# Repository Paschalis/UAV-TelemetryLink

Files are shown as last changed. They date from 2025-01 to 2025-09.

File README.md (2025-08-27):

# Custom RX/TX Board Designs for GCS Communication

<p align="center">
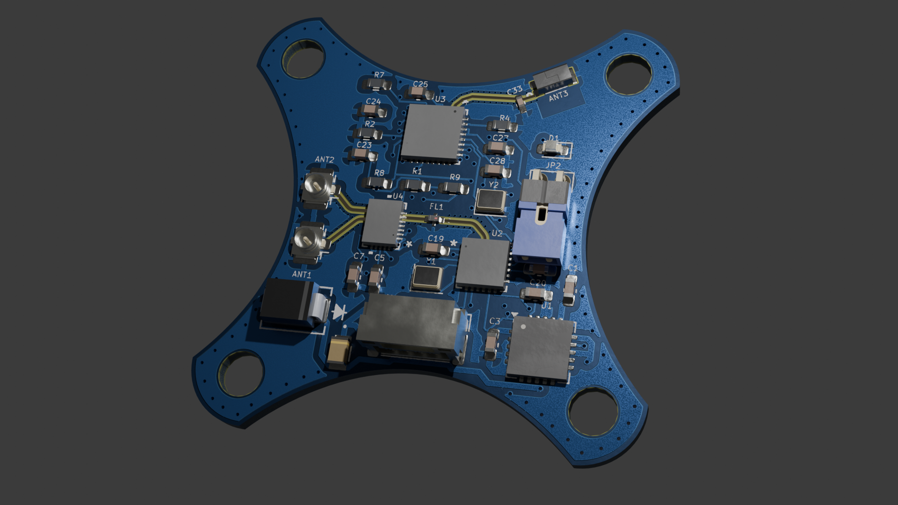
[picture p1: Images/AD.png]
preview
  
</p>

**Receiver and transmitter solution for Ground Control Stations (GCS)**, designed to provide reliable telemetry and control using ELRS, mLRS, and MAVLink protocols. This repository features a wide range of innovative board designs, optimized for long-range communication, minimal latency, and robust performance under varying conditions. From Antenna Diversity to True Diversity and Gemini Mode boards, these designs cater to diverse operational needs and ensure seamless integration with UAV systems. Explore our RX and TX boards tailored to meet the demands of modern UAV telemetry and control systems.

## Table of Contents

1. [QGroundControl Integration](#qgroundcontrol-integration)
2. [Board Designs Overview](#board-designs-overview)
    1. [Antenna Diversity Boards](#1-antenna-diversity-boards)
    - [RX Boards](#rx-boards)
    - [TX Boards](#tx-boards)
    2. [True Diversity or Full Diversity Boards](#2-true-diversity-or-full-diversity-boards)
    - [RX Boards](#rx-boards-1)
    - [TX Boards](#tx-boards-1)
    3. [Gemini Mode Boards](#3-gemini-mode-boards)
    - [RX Boards](#rx-boards-2)
    - [TX Boards](#tx-boards-2)
    4. [Gemini Xrossband (GemX) Boards](#4-gemini-xrossband-gemx-boards)
    - [RX Boards](#rx-boards-3)
    - [TX Boards](#tx-boards-3)
3. [Contributing](#contributing)
4. [Acknowledgments](#acknowledgments)
5. [License](#license)

## QGroundControl Integration

QGroundControl (QGC) is a powerful tool for mission planning and UAV control. This section demonstrates how to use the boards in this repository for telemetry and control with QGC, even without an RC controller.

### Using ELRS Boards with QGC
1. Connect the ground-based ELRS receiver to your GCS using a USB-to-UART adapter.
2. Ensure telemetry is enabled on your flight controller and configured for ELRS.
3. Launch QGC, and verify telemetry data is being received.

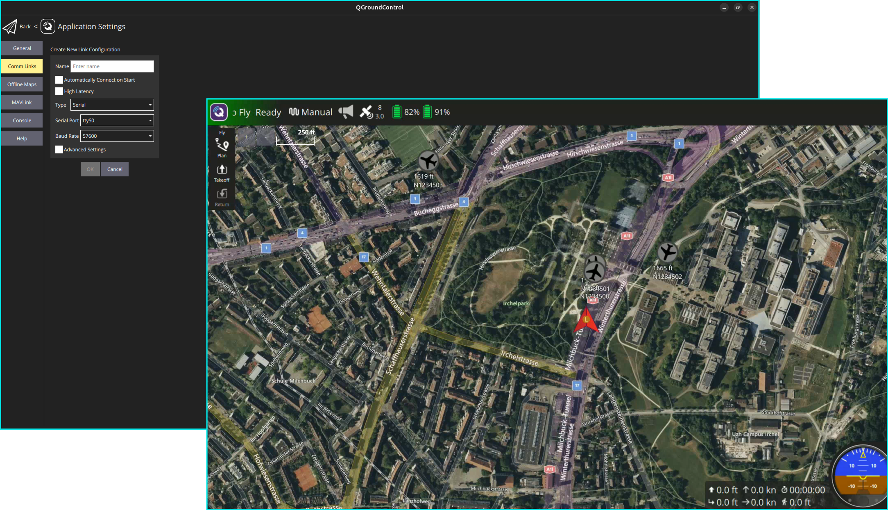
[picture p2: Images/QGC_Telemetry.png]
QGC Interface


### Hardware Setup
Below is an example of the hardware setup for mission planning:
- **Ground Setup**: ELRS transmitter connected to the GCS via USB or mounted on the RC controller.
- **Onboard Setup**: ELRS receiver mounted on the UAV and connected to the flight controller.

Hardware Setup

> **Note:**  
> - More details about the transmission modes can be found in the [Transmission Modes Classification](Receivers%20and%20Transmitters/README.md).
>
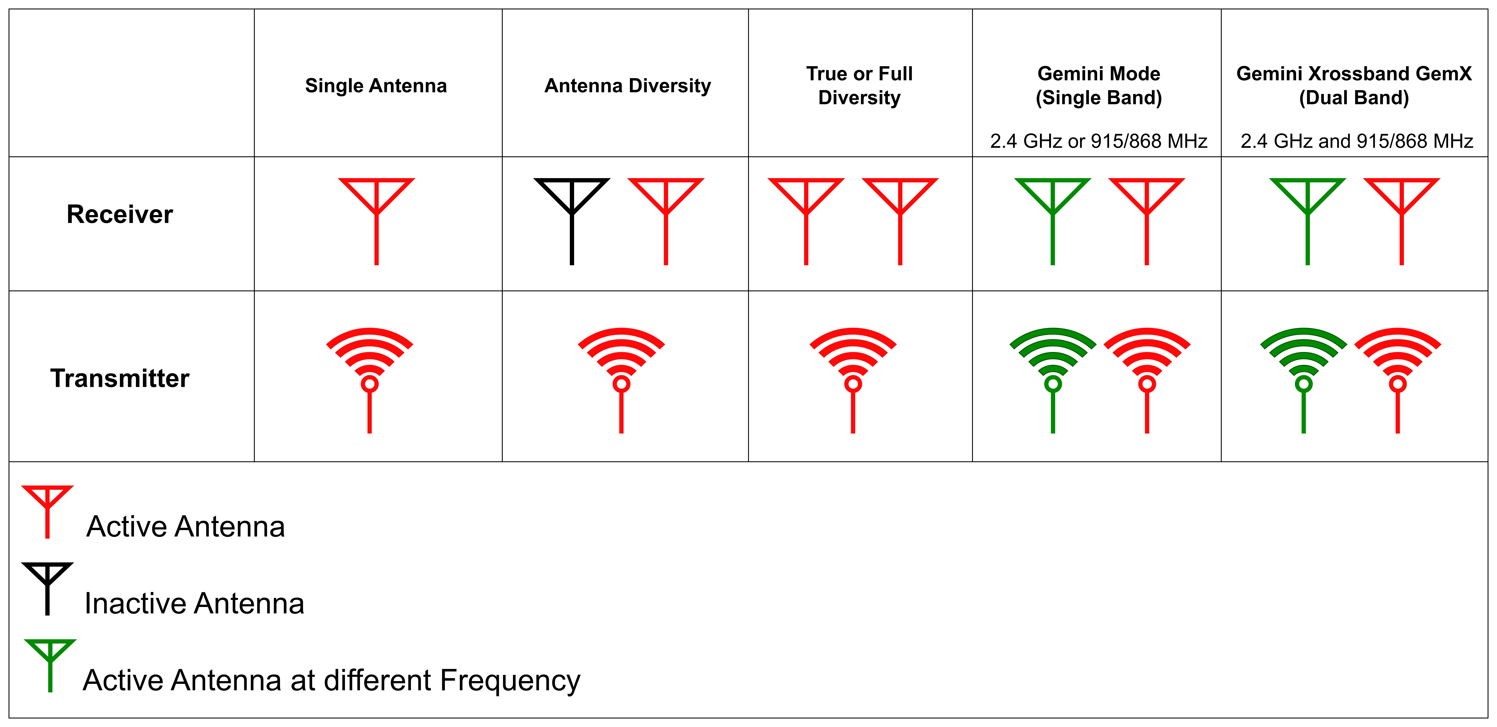
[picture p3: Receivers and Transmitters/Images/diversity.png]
Modes Info
>

> **Note:**  
> - ELRS requires proper binding and configuration to function as a telemetry link.

GCS

## Related Projects (click on them to expand)

<!-- <p align="center"><em>(click on them to expand)</em></p> -->

<ol style="line-height: 2;">
   <li><details open>
   <summary><strong>ESP32 UAV Telemetry Monitor</strong></summary>

An ESP32-based telemetry display system for real-time MAVLink UAV monitoring, featuring a responsive touchscreen interface, live flight status visualization, OTA firmware update capability, and seamless integration with QGroundControl, MAVProxy, and other MAVLink-compatible ground stations.
<div align="center">

MonitorPreview

  
  

</div>

   </details></li>
   <li><details>
   <summary><strong>FC Plus Sensor Module</strong></summary>


FC Plus Sensor Module is a modular add-on board for UAV flight controllers, offering advanced features such as telemetry, GPS, object avoidance (ToF, Sonar, IR), and LED indicators for status feedback. This repository includes comprehensive documentation, hardware setup instructions, sensor integration guides, and communication protocols (LoRa/WiFi) to improve UAV autonomy, safety, and performance.

<div align="center">

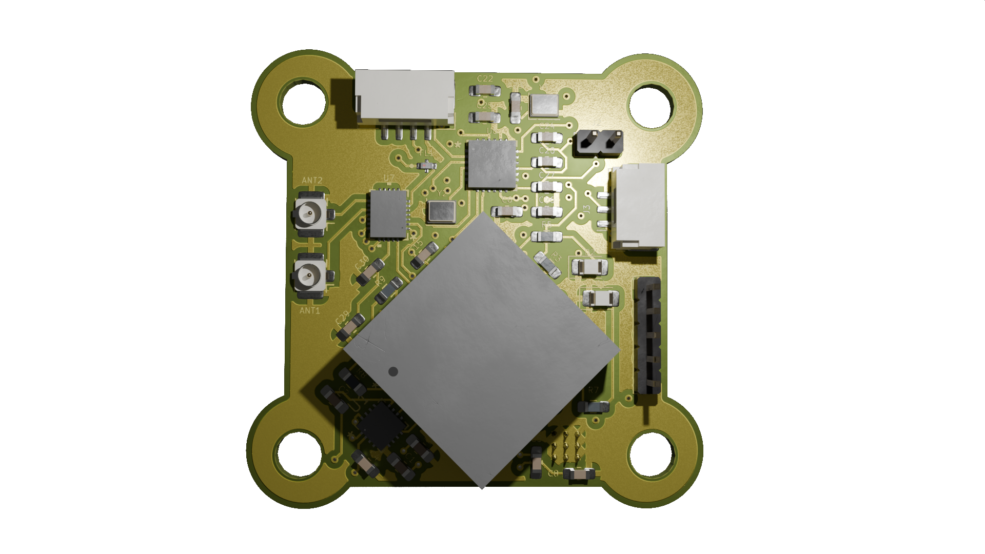
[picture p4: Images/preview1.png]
FCreview



              
  

</div>

</ol>

# Board Designs Overview

This repository contains a collection of designs for RX and TX boards under different transmission modes. More details about the transmission modes can be found in the [Transmission Modes Classification](Receivers%20and%20Transmitters/README.md).

<p align="center">
    <a href="https://Paschalis.github.io/UAV-TelemetryLink/" target="_blank">
        
    </a>
</p>

<div style="overflow-x:auto;">

### 1. Antenna Diversity Boards

### RX Boards

#### ELRS

| Name | Frequency | Version | Features | Media | Status |
|---|---|---|---|---|---|
| AD1_2.4G  | 2.4GHz | Rev 1.0 | Basic diversity setup | <p align="center">Preview<br/> </p> | <p align="center">✅ Approved</p> |
| AD2_900M  | 900MHz | Rev — | (Add description) | <p align="center">Preview<br/>(Add links)</p> | <p align="center">Draft</p> |

</div>

<div style="overflow-x:auto;">

## 2. True Diversity or Full Diversity Boards

### RX Boards

| Name | Frequency | Version | Features | Media | Status |
|---|---|---|---|---|---|
| TD1_2.4G  | 2.4GHz | Rev 1.0 | Full diversity with improved range | <p align="center">Preview<br/> </p> | <p align="center">✅ Approved</p> |
| TD2_900M  | 900MHz | Rev 0.9 | (Add description) | <p align="center">Preview<br/>(Add links)</p> | <p align="center">Draft</p> |

</div>

## TX Boards (Shared for Single Antenna, Antenna Diversity & True Diversity)
<div align="center">

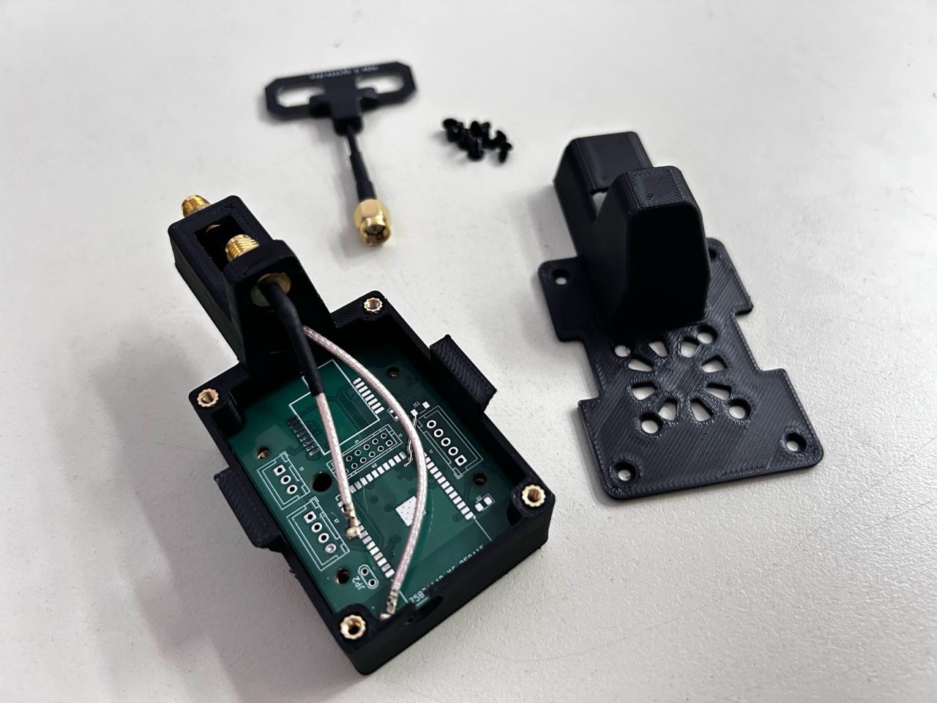
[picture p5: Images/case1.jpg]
MonitorPreview


[📂 Click here to open the enclosure files](https://github.com/Paschalis/UAV-TelemetryLink/tree/main/Receivers%20and%20Transmitters/Transmitters/Mechanical%20CAD)

MonitorPreview

</div>

> **Note:**  
> The TX boards listed in this section are shared across **Single Antenna Mode, Antenna Diversity, and True Diversity** configurations.  
> - These boards are **not duplicated** under each diversity category to avoid redundancy.  
> - They are optimized for their respective frequencies (**2.4GHz** & **900MHz**) and ensure compatibility across all three configurations.  
> - **Gemini Mode (GM) and Gemini Xrossband (GemX) have their own TX boards**, so they are listed separately in their respective sections.  

<div style="overflow-x:auto;">

### TX Boards  

| Name | Frequency | Version | Features | Media | Status |
|---|---|---|---|---|---|
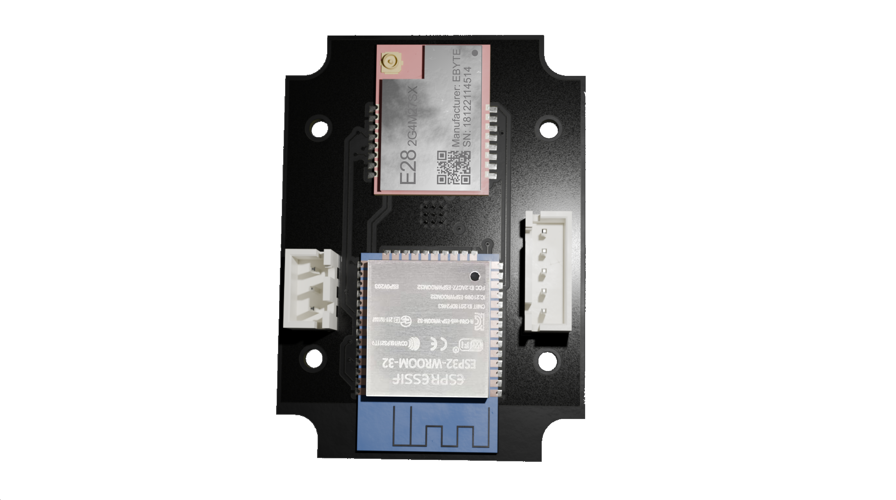
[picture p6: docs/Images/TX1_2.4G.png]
| TX1_2.4G  | 2.4GHz | Rev 1.0 | Basic transmitter with no OLED display or TX Backpack. | <p align="center"><br/> </p> | <p align="center">✅ Approved</p> |
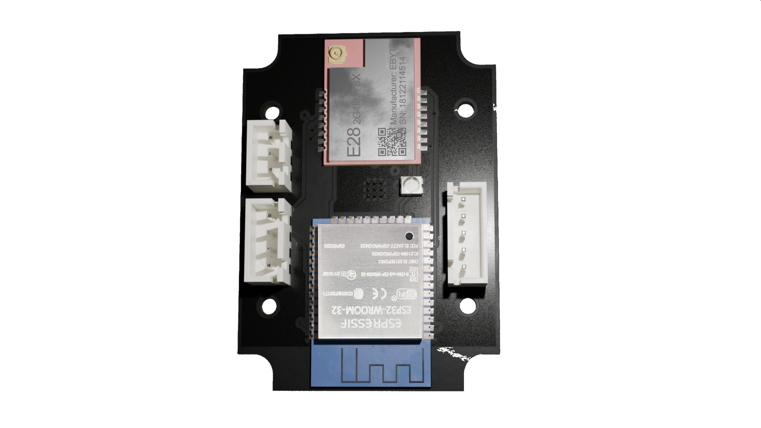
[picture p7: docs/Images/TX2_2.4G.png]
| TX2_2.4G  | 2.4GHz | Rev 1.1 | Includes SSD1306 OLED display, but no TX Backpack. | <p align="center"><br/> </p> | <p align="center">✅ Approved</p> |
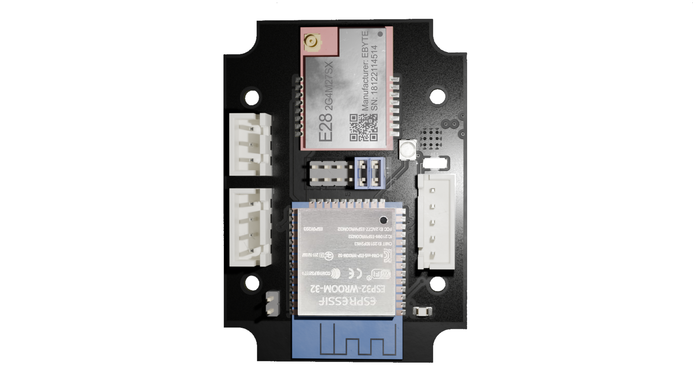
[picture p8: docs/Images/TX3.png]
| TX3_2.4G  | 2.4GHz | Rev 1.2 | Features both SSD1306 OLED display and TX Backpack for GCS communication.| <p align="center"><br/> </p> | <p align="center">Draft</p> |
| TX1_900M  | 900MHz | Rev 1.0 | Robust transmitter for 900MHz band, suitable for longer-range links. | <p align="center">Preview<br/> </p> | <p align="center">Draft</p> |

</div>

## 3. Gemini Mode Boards  

### RX Boards
> **Note:**  
> - The **Gemini RX boards** are actually the **True Diversity RX boards** operating in **Gemini Mode**.  
> - To enable **Gemini Mode**, set the **RX Antenna Mode** to **Gemini** via Lua script.  
> - **Single Antenna RX boards** can also operate in Gemini Mode but must use **Model 5** in **Model Config Matching** via Lua script.  
> - **Gemini-capable receivers** should use **Model 6** in **Model Config Matching**.  
> - Click on [🔗 **Go to True Diversity Full Diversity RX Boards**](#2-true-diversity-or-full-diversity-boards) to view compatible receivers.  
>  
> 📖 **Reference:** [ExpressLRS Gemini Mode Documentation](https://www.expresslrs.org/software/gemini/#what-is-gemini)  

<div style="overflow-x:auto;">

### TX Boards (Gemini Mode – Single Band)

| Name | Frequency | Version | Features | Media | Status |
|---|---|---|---|---|---|
| G_TX1_2.4G  | 2.4GHz | Rev 1.0 | Sends packets on two frequencies ~40 MHz apart in the 2.4 GHz band. | <p align="center">Preview<br/> </p> | <p align="center">✅ Approved</p> |
| G_TX1_900M  | 900MHz | Rev 1.0 | Sends packets on two frequencies ~10 MHz apart in the 900 MHz band. | <p align="center">Preview<br/> </p> | <p align="center">Draft</p> |

</div>

<div style="overflow-x:auto;">

## 4. Gemini Xrossband (GemX) Boards  

### RX Boards  

| Name  | Frequency | Version | Features | Media | Status |
|---|---|---|---|---|---|
| GX1 | 2.4GHz & 900MHz  | Rev 1.0 | Crossband receiver for 2.4GHz and 900MHz | <p align="center">Preview (https://github.com/your-repo/boards/GX1)<br/> </p> | <p align="center">Draft</p> |

### TX Boards  

| Name | Frequency | Version | Features | Media | Status |
|---|---|---|---|---|---|
| GX_TX1 | 2.4GHz & 900MHz  | Rev 1.0 | Crossband transmitter for 2.4GHz and 900MHz | <p align="center">Preview (https://github.com/your-repo/boards/GX_TX1)<br/> </p> | <p align="center">Draft</p> |

</div>

## Contributing

Feel free to contribute to this repository by submitting pull requests for new board designs or updates to existing ones.

## Acknowledgments

We would like to thank the following for making this project possible:

- **ELRS (ExpressLRS)**: High-performance, low-latency long-range communication for UAVs.  
- **mLRS (MAVLink Long Range System)**: MAVLink-based long-range telemetry and control extension for ELRS.  
- **MAVLink**: The essential protocol for UAV communication and mission control.  
- **QGroundControl (QGC)**: Open-source ground control software for UAV mission planning. 
- **OpenTX**: Open-source firmware for RC transmitters, enabling extensive customization and telemetry support.  
- **OpenI6X**: A custom OpenTX / EdgeTX port for the Flysky FS-i6X transmitter, expanding its capabilities and MAVLink support.   
- **Other Contributors**: Thanks to all who contributed feedback, bug fixes, and improvements.

These open-source tools and protocols are integral to the success of this project.

## License

This project is licensed under the following:

- **Hardware Designs**: MIT License - see the [LICENSE-HARDWARE](LICENSE-HARDWARE) file for details.
- **Firmware/Software**: GPLv3 License - see the [LICENSE-FIRMWARE](LICENSE-FIRMWARE) file for details.

> **Note:**  
> The firmware you flash onto the hardware uses the **ELRS** and **mLRS**, which are licensed under **GPLv3**. Any modifications or redistribution of the firmware must comply with the terms of the **GPLv3** license.

---

**Thank you for visiting UAV-TelemetryLink!**

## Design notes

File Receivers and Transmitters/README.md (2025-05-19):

# Transmission Modes Classification

Gemini Info

This document describes various transmission modes used in long-range LoRa (Long Range) wireless communication for drones. These modes leverage LoRa's unique capabilities to improve Signal Quality (LQ), mitigate interference, and enhance reliability over extended distances, making them ideal for drone applications in diverse environments.

## Transmission Modes

### 1. Single Antenna
- **Description**:  
  Uses one antenna on both the transmitter and receiver, operating over a single frequency channel.
- **Advantages**:  
  - Simplicity  
  - Low cost  
- **Limitations**:  
  - Highly susceptible to interference and signal loss.  

### 2. Antenna Diversity
- **Description**:  
  The receiver employs two antennas to select the best signal, while the transmitter uses a single antenna. Communication occurs over a single frequency channel.  
- **Advantages**:  
  - Improved signal quality due to antenna selection.  
- **Limitations**:  
  - Only one frequency channel is used.  
  - Transmission lacks diversity.  

### 3. True Diversity or Full Diversity
- **Description**:  
  Both the transmitter and receiver utilize two independent Semtech LoRa chips, each connected to its own antenna, operating on the same frequency. This setup provides full diversity for both transmitting and receiving.  
- **Advantages**:  
  - Enhanced signal quality through full transmitter and receiver diversity.  
  - Redundancy in signal transmission and reception.  
- **Limitations**:  
  - Increased complexity and cost.  

### 4. Gemini Mode (Single Band)
- **Description**:  
  The transmitter sends packets on two frequencies within the same band (e.g., 2.4 GHz or 900 MHz), spaced approximately 40 MHz apart for 2.4 GHz and 10 MHz apart for 900 MHz. A true diversity receiver with two antennas and LoRa chips receives both signals simultaneously.  
- **Advantages**:  
  - Superior interference mitigation by utilizing two frequencies within the same band.  
  - Improved stability and reliability of signal quality.  
- **Limitations**:  
  - Limited to a single frequency band.  

### 5. Gemini Xrossband GemX (Dual Band)
- **Description**:  
  The transmitter operates simultaneously on two different frequency bands (e.g., 2.4 GHz and 900 MHz), each managed by independent LoRa chips. The receiver employs true diversity hardware with two antennas and LoRa chips operating on distinct bands.  
- **Advantages**:  
  - Enhanced interference avoidance by operating across separate bands.  
  - Increased performance and redundancy for long-range communication.  
- **Limitations**:  
  - More complex and expensive hardware due to dual-band operation.  

## Transmission Mode Classification Chart

| Mode | Frequency Channels | Antennas (TX) | Antennas (RX)| Interference Mitigation | Signal Quality  | Receiver Type |
|---|---|---|---|---|---|---|
| **Single Antenna** | 1 | 1 | 1 | Low | Low | Simple Receiver |
| **Antenna Diversity** | 1 | 1 | 2 | Moderate | Moderate | Diversity Receiver |
| **True Diversity or Full Diversity**  | 1 | 1 | 2 | High | High | Diversity Receiver |
| **Gemini Mode (Single Band)**| 2 (within 1 band) | 2 | 2 | Very High | Very High | Diversity Receiver |
| **Gemini Xrossband GemX (Dual Band)** | 2 (across 2 bands) | 2 | 2 | Excellent | Excellent | Dual-band Receiver |

## Summary

This classification illustrates the progression from basic single antenna setups to advanced true diversity and dual-band configurations:

- **Single Antenna** and **Antenna Diversity** provide fundamental solutions suitable for simple environments.  
- **True Diversity** or **Full Diversity** and **Gemini Mode (Single Band)** offer significant enhancements in reliability and interference mitigation within the same band.  
- **Gemini Xrossband GemX (Dual Band)** delivers optimal performance by leveraging dual-band communication, ideal for complex and interference-prone environments.  

Understanding these modes enables the selection of appropriate communication systems tailored to specific drone operation requirements, ensuring robust and efficient wireless links.

## Mounting and Enclosure Options

For practical deployment of the transmission systems described above, especially those involving Moxon or omnidirectional antennas operating at 2.4 GHz and 900 MHz, refer to the [TX_Enclosures_RC_Mounts](/Receivers%20and%20Transmitters/Transmitters/TX_Enclosures_RC_Mounts/) folder.

This directory contains 3D-printable enclosures and RC controller mounting designs for various transmitter boards. These mounts are optimized for signal performance, mechanical stability, and operator ergonomics across all transmission modes, from single antenna to Gemini Xrossband setups.

---

## References

- [mLRS GitHub Repository](https://github.com/olliw42/mLRS)  
- [mLRS Documentation](https://github.com/olliw42/mLRS-docu)  
- [mLRS Hardware Repository](https://github.com/olliw42/mLRS-hardware/tree/master)  
- [ArduPilot: mLRS RC Overview](https://ardupilot.org/copter/docs/common-mlrs-rc.html)  
- [ExpressLRS: Gemini Overview](https://www.expresslrs.org/software/gemini/)  
- [ExpressLRS Documentation](https://www.expresslrs.org/)  

[⬅️ Go Back to Main README](../README.md)

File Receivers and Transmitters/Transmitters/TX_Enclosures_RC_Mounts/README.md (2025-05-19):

# TX Enclosures and RC Controller Mounts

This folder contains 3D-printable enclosures and mounting systems for transmitter boards used in long-range LoRa communication systems. These designs are intended to be mounted securely on RC controllers or other ground station platforms, ensuring optimal antenna placement, signal integrity, and protection of the electronics.

## 📦 Included Designs

Each mount or enclosure is optimized for both mechanical stability and RF performance, and is designed to accommodate the following:

- **Transmitter types:**
  - TX1, TX2, TX3 (2.4GHz)
  - G_TX1 (Gemini 2.4GHz / 900MHz)
  - GX_TX1 (Gemini Xrossband 2.4GHz + 900MHz)

- **Antenna support:**
  - Moxon directional antennas (for reduced side lobe interference)
  - Omnidirectional vertical whips (for all-direction reception)
  - Mounts for both upright and tilted antenna positions

## 📐 File Format Notes

- Files are provided in `.STL` format for direct 3D printing.
- - Some designs also include `.STEP`, `.Fusion360`, or SolidWorks-compatible files (`.SLDPRT`, `.SLDASM`) for customization.
- Be sure to orient the print flat on the base and use moderate infill (25–40%) for strength without excessive weight.

## Previews

## License

All 3D models and designs are released under the [CERN Open Hardware License v2](https://ohwr.org/project/cernohl/wikis/home), allowing you to modify, share, and produce them for personal or commercial use, provided attribution is given and derivatives are shared alike.

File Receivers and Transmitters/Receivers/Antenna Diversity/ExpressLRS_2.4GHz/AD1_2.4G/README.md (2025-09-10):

<div align="center">

# AD1_2.4G

Antenna Diversity 
(Basic diversity setup)

</div>

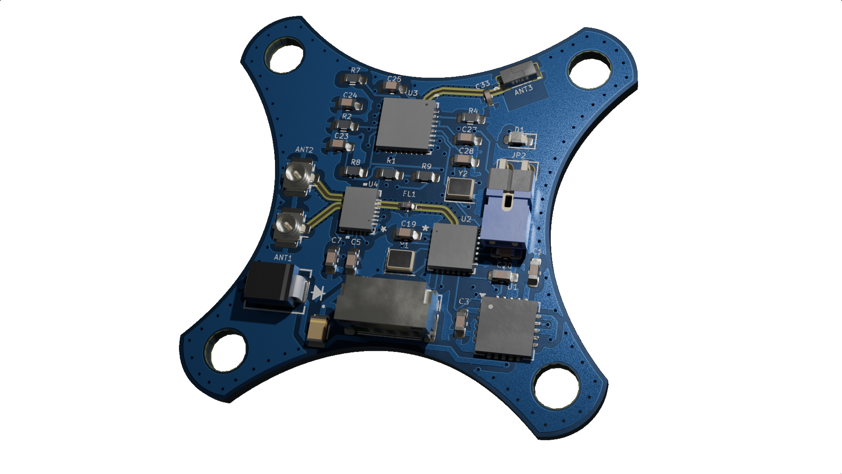
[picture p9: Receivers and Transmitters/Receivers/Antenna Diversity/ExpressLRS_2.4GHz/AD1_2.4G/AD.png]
Board Preview


<p align="center"><a href="https://paschalis.github.io/UAV-TelemetryLink/ibom/AD1_2.4G.html">iBOM</a> or <a href="https://kicanvas.org/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">KiCanvas</a></p>  <p align="center">Click the icons to open iBOM or KiCanvas</p> 

## Bill of Materials

| **Reference** | **Value** | **Datasheet** | **Footprint** | **Qty** | **DNP** |
|---|---|---|---|---|---|
| AE1 | Antenna | ~ | RF_Antenna:Texas_SWRA117D_2.4GHz_Right | 1  | |
| ANT1, ANT2  | Conn_Coaxial | ~ | Connector_Coaxial:U.FL_Hirose_U.FL-R-SMT-1_Vertical | 2  | |
| C1, C30, C32 | 10uF | ~ | Capacitor_SMD:C_0805_2012Metric_Pad1.18x1.45mm_HandSolder,ECASD40J106M055K00:ECASD40J106M055K00 | 3  | |
| C2 | 1uF | ~ | Capacitor_SMD:C_0805_2012Metric_Pad1.18x1.45mm_HandSolder | 1  | |
| C3 | 47uF | ~ | Capacitor_SMD:C_0805_2012Metric_Pad1.18x1.45mm_HandSolder | 1  | |
| C4 | 2.2uF | ~ | Capacitor_SMD:C_0805_2012Metric_Pad1.18x1.45mm_HandSolder | 1  | |
| C5, C6, C21, C22 | 10pF | ~ | Capacitor_SMD:C_0805_2012Metric_Pad1.18x1.45mm_HandSolder | 4  | |
| C7, C16, C17, C23, C24, C25, C26, C27, C28, C29 | 100nF | ~ | Capacitor_SMD:C_0805_2012Metric_Pad1.18x1.45mm_HandSolder | 10 | |
| C18 | 470nF | ~ | Capacitor_SMD:C_0805_2012Metric_Pad1.18x1.45mm_HandSolder | 1  | |
| C19, C20 | 10nF | ~ | Capacitor_SMD:C_0805_2012Metric_Pad1.18x1.45mm_HandSolder | 2  | |
| C31 | 0.1uF | ~ | Capacitor_SMD:C_0805_2012Metric_Pad1.18x1.45mm_HandSolder | 1  | |
| D1 | LED | ~ | LED_SMD:LED_0805_2012Metric_Pad1.15x1.40mm_HandSolder | 1  | |
| FL1 | 2450FM07D0034T  | [Datasheet](https://www.mouser.co.uk/datasheet/2/611/2450FM07D0034-1375634.pdf) | 2450FM07D0034T:2450FM07D0034T | 1 | |
| J1 | Conn_01x04_Socket | ~ | Connector_Harwin:Harwin_M20-89004xx_1x04_P2.54mm_Horizontal | 1  | |
| J3 | Conn_01x04_Pin  | ~ | Connector_JST:JST_GH_SM04B-GHS-TB_1x04-1MP_P1.25mm_Horizontal | 1  | |
| JP1 | Jumper_2_Bridged | ~ | TestPoint:TestPoint_2Pads_Pitch2.54mm_Drill0.8mm | 1  | |
| R1 | 2.2K | ~ | Resistor_SMD:R_0805_2012Metric_Pad1.20x1.40mm_HandSolder | 1  | |
| R2, R3, R7, R8, R10 | 10K | ~ | Resistor_SMD:R_0805_2012Metric_Pad1.20x1.40mm_HandSolder | 5  | |
| R4 | 12K | ~ | Resistor_SMD:R_0805_2012Metric_Pad1.20x1.40mm_HandSolder | 1  | |
| R5 | 0 | ~ | Resistor_SMD:R_0805_2012Metric_Pad1.20x1.40mm_HandSolder | 1  | |
| R6 | 1K | ~ | Resistor_SMD:R_0805_2012Metric_Pad1.20x1.40mm_HandSolder | 1  | |
| R9 | 1.2K | ~ | Resistor_SMD:R_0805_2012Metric_Pad1.20x1.40mm_HandSolder | 1  | |
| U1 | TPS7A4701xRGW | [Datasheet](https://www.ti.com/lit/ds/symlink/tps7a47.pdf) | Package_DFN_QFN:Texas_RGW0020A_VQFN-20-1EP_5x5mm_P0.65mm_EP3.15x3.15mm_ThermalVias | 1 | |
| U2 | SX1280IMLTRT | SX1280IMLTRT | SX1280IMLTRT:QFN24_4X4_SEM | 1 | |
| U3 | ESP8285H16 | ESP8285H16 | ESP8285H16:QFN32_5X5_EXP | 1 | |
| U4 | SE2431L-R | SE2431L-R | SE2431L-R:SE2431L_SKY | 1 | |
| Y1 | 52MHz | ~ | Crystal:Crystal_SMD_2016-4Pin_2.0x1.6mm | 1 | |
| Y2 | 26MHz | ~ | Crystal:Crystal_SMD_2016-4Pin_2.0x1.6mm | 1 | |

[⬅️ Go Back to Main README](https://github.com/Paschalis/UAV-TelemetryLink)

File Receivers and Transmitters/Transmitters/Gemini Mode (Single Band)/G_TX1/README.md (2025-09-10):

<div align="center">

# G_TX1 at 2.4G

TRANSMITTER BOARD
(Gemini Mode Compatible)

</div>

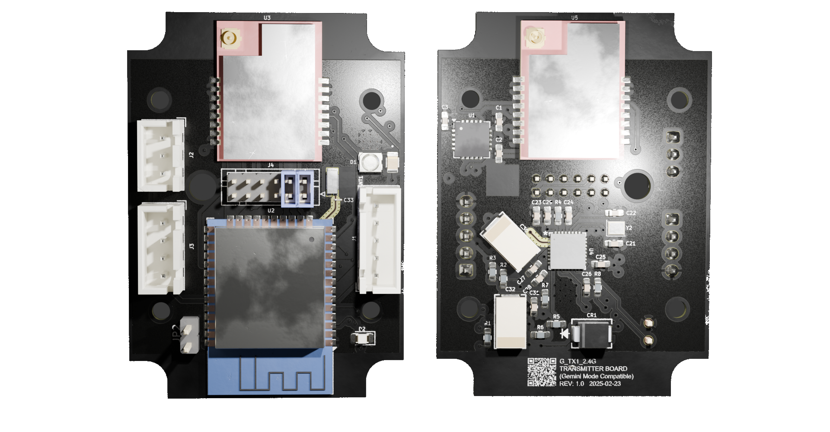
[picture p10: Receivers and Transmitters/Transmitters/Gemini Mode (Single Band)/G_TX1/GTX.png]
Board Preview

<p align="center"><a href="https://paschalis.github.io/UAV-TelemetryLink/ibom/G_TX1_2.4G.html">iBOM</a> or <a href="https://kicanvas.org/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">KiCanvas</a></p>  <p align="center">Click the icons to open iBOM or KiCanvas</p> 

[⬅️ Go Back to Main README](https://github.com/Paschalis/UAV-TelemetryLink)

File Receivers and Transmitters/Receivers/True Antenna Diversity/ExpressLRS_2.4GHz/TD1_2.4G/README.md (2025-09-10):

<div align="center">

# TD1 at 2.4G

True Diversity or Full Diversity
(Full diversity with improved range)

</div>

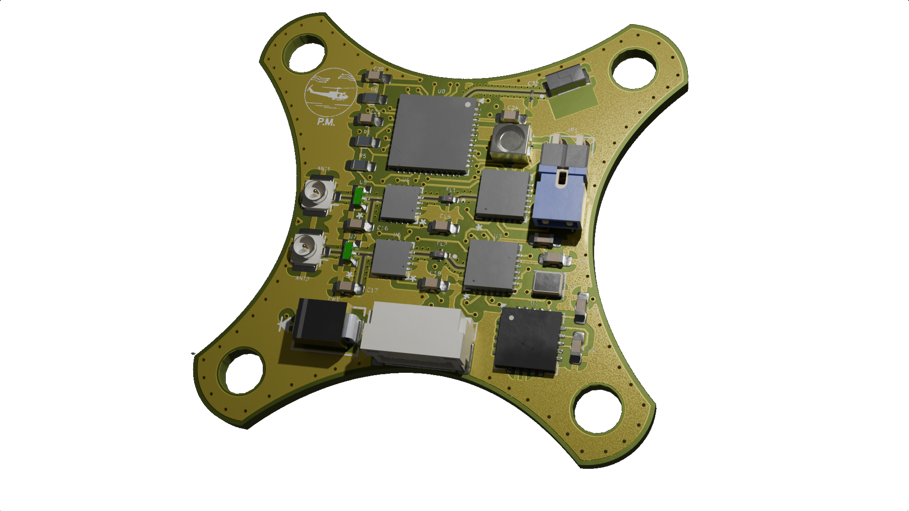
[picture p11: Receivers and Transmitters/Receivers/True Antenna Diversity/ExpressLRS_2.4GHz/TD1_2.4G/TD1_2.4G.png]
Board Preview

<p align="center"><a href="https://paschalis.github.io/UAV-TelemetryLink/ibom/TD1_2.4G.html">iBOM</a> or <a href="https://kicanvas.org/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">KiCanvas</a></p>  <p align="center">Click the icons to open iBOM or KiCanvas</p> 

[⬅️ Go Back to Main README](https://github.com/Paschalis/UAV-TelemetryLink)

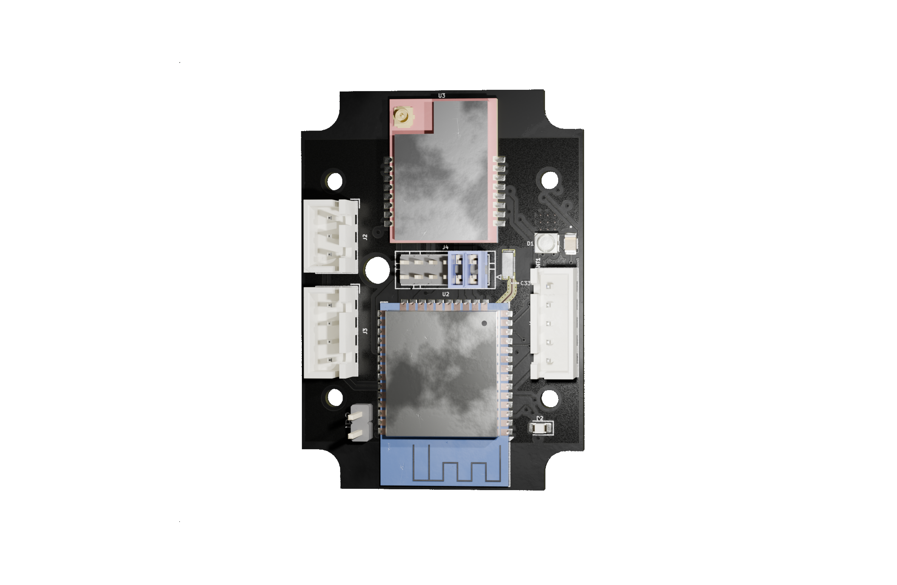
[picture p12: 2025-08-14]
docs/Images/G_TX1_2.4G.png

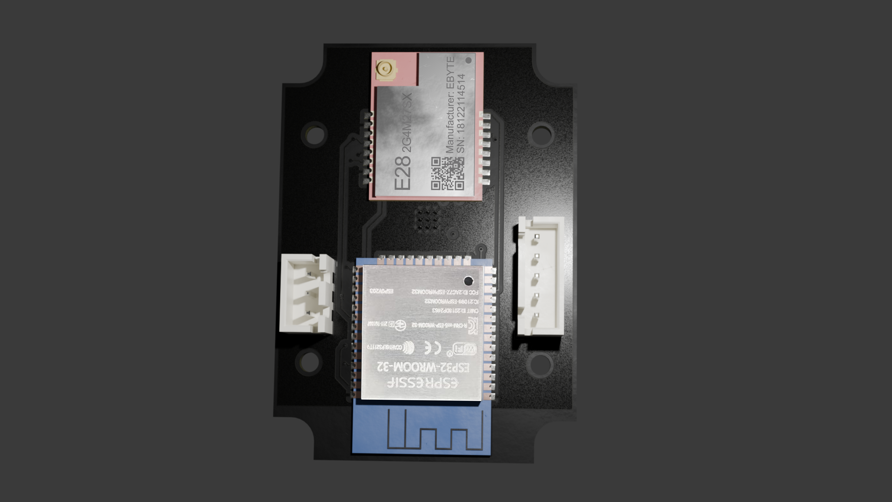
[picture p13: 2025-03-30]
Receivers and Transmitters/Transmitters/Shared for Single Antenna, Antenna Diversity, True or Full Diversity/ExpressLRS_2.4GHz/TX1_2.4G/TX1.png

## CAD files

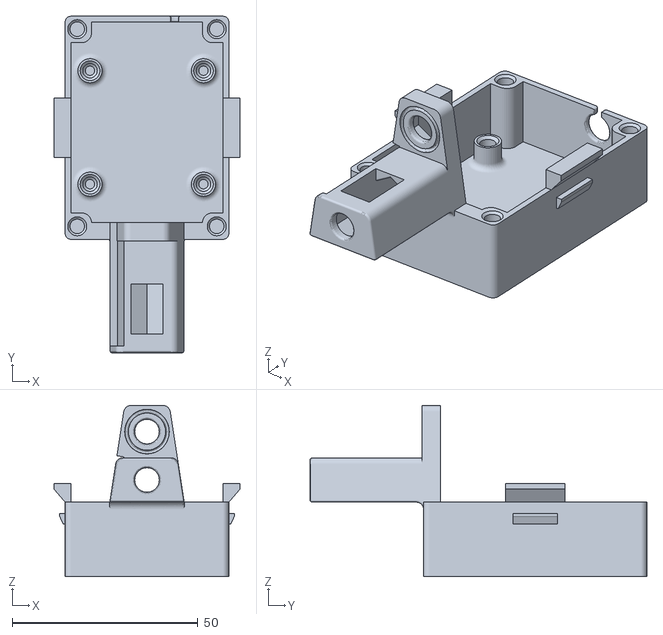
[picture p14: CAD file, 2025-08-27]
Receivers and Transmitters/Transmitters/Mechanical CAD/Enclosure_Bottom.stl
50.0 x 90.5 x 46.0

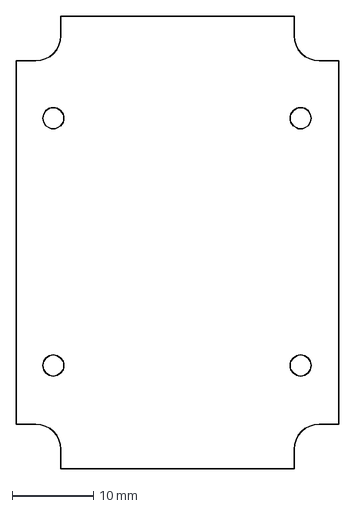
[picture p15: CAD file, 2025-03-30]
Receivers and Transmitters/Transmitters/PCB outline/(PCB outline) V1_Matek_mLRS-JRBay-btm (with PCB mounting).DXF
39.8 x 55.8 mm

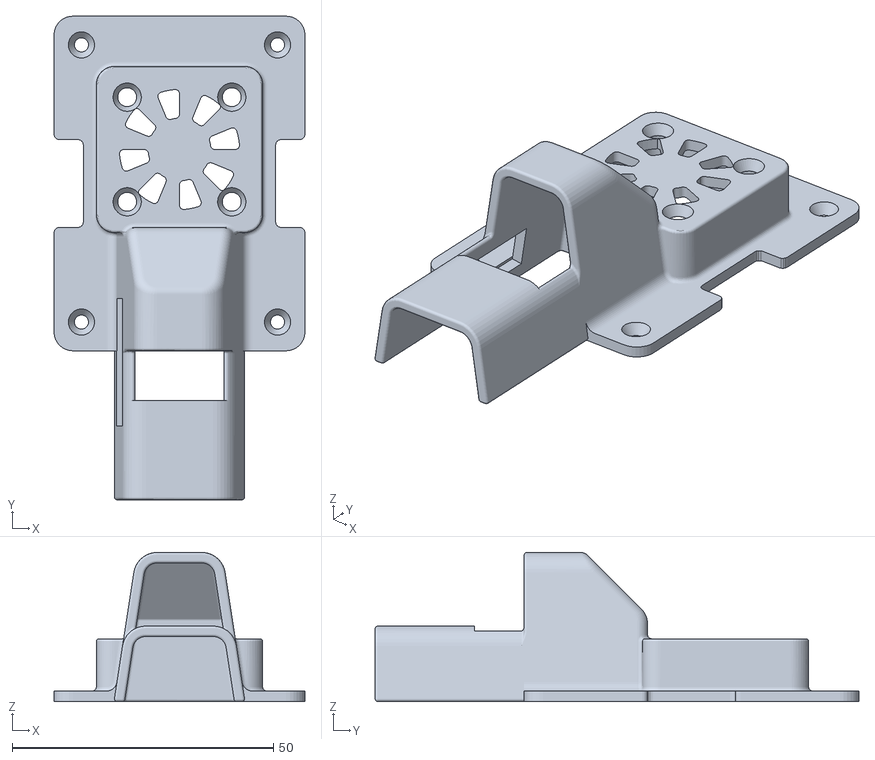
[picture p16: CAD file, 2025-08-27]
Receivers and Transmitters/Transmitters/Mechanical CAD/Enclosure_Top.stl
48.0 x 92.5 x 28.5

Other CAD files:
Receivers and Transmitters/Transmitters/Mechanical CAD/V1.2 (Top_Bottom_Offset)_mLRS-JRBay-btm.STL

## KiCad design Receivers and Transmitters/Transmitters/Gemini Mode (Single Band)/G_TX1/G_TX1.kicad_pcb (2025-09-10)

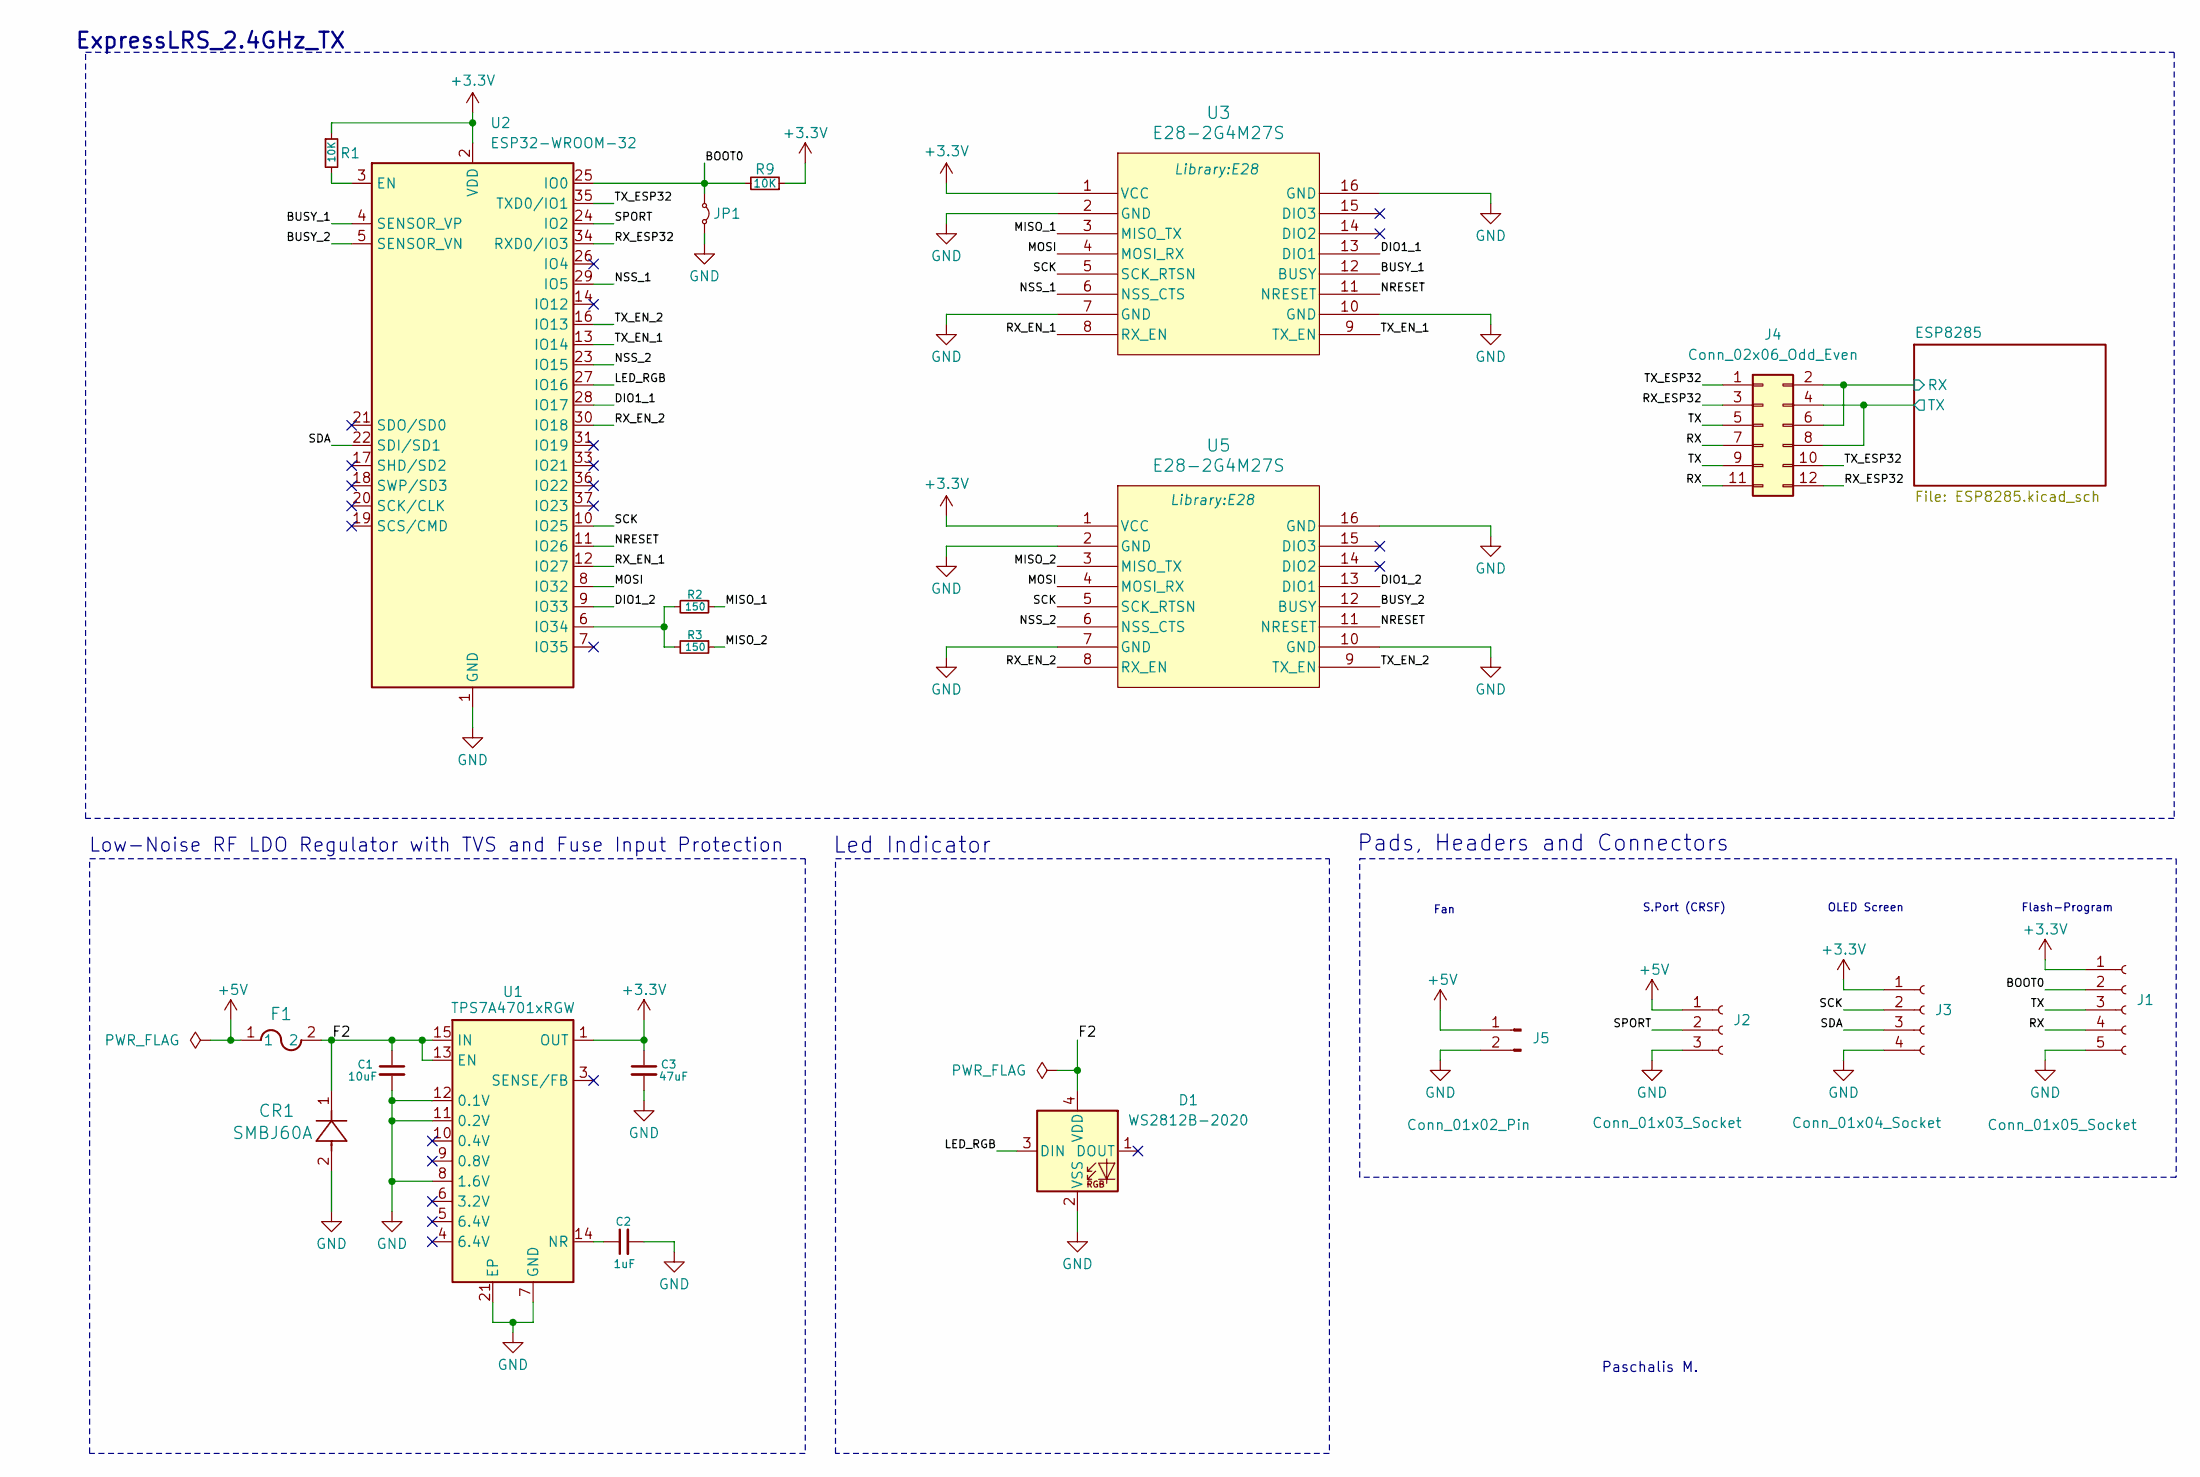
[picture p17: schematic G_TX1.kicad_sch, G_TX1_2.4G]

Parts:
C1: 10uF; C_0603_1608Metric_Pad1.08x0.95mm_HandSolder
C2: 1uF; C_0603_1608Metric_Pad1.08x0.95mm_HandSolder
C3: 47uF; C_0603_1608Metric_Pad1.08x0.95mm_HandSolder
CR1: SMBJ60A; SMBJSeries_LTF
D1: WS2812B-2020; LED_WS2812B-2020_PLCC4_2.0x2.0mm
F1: MF-PSMF020X-2; FUSE_F020X_BRN
J1: Conn_01x05_Socket; JST_XH_B5B-XH-A_1x05_P2.50mm_Vertical
J2: Conn_01x03_Socket; JST_XH_B3B-XH-A_1x03_P2.50mm_Vertical
J3: Conn_01x04_Socket; JST_XH_B4B-XH-A_1x04_P2.50mm_Vertical
J4: Conn_02x06_Odd_Even; JST_PHD_B12B-PHDSS_2x06_P2.00mm_Vertical
J5: Conn_01x02_Pin; PinHeader_1x02_P2.00mm_Vertical
JP1: Jumper_2_Small_Bridged; TestPoint_2Pads_Pitch2.54mm_Drill0.8mm
R1, R9: 10K; R_0603_1608Metric_Pad0.98x0.95mm_HandSolder
R2, R3: 150; R_0603_1608Metric_Pad0.98x0.95mm_HandSolder
U1: TPS7A4701xRGW; Texas_RGW0020A_VQFN-20-1EP_5x5mm_P0.65mm_EP3.15x3.15mm_Ther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
U2: ESP32-WROOM-32
U3, U5: E28-2G4M27S; E28

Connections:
+3.3V: C3.1, J1.1, J3.1, R1.1, R9.1, U1.1 (OUT), U1.20 (OUT), U2.2 (VDD), U3.1 (VCC), U5.1 (VCC); also elsewhere on the board
+5V: F1.1, J2.1, J5.1
/BOOT0: J1.2, JP1.1 (A), R9.2, U2.25 (IO0)
/BUSY_1: U2.4 (SENSOR_VP), U3.12 (BUSY)
/BUSY_2: U2.5 (SENSOR_VN), U5.12 (BUSY)
/DIO1_1: U2.28 (IO17), U3.13 (DIO1)
/DIO1_2: U2.9 (IO33), U5.13 (DIO1)
/ESP8285/RX: J4.2, J4.6; also elsewhere on the board
/ESP8285/TX: J4.4, J4.8; also elsewhere on the board
/F2: C1.1, CR1.1, D1.4 (VDD), F1.2, U1.13 (EN), U1.15 (IN), U1.16 (IN)
/LED_RGB: D1.3 (DIN), U2.27 (IO16)
/MISO_1: R2.1, U3.3 (MISO_TX)
/MISO_2: R3.1, U5.3 (MISO_TX)
/MOSI: U2.8 (IO32), U3.4 (MOSI_RX), U5.4 (MOSI_RX)
/NRESET: U2.11 (IO26), U3.11 (NRESET), U5.11 (NRESET)
/NSS_1: U2.29 (IO5), U3.6 (NSS_CTS)
/NSS_2: U2.23 (IO15), U5.6 (NSS_CTS)
/RX: J1.4, J4.7, J4.11
/RX_EN_1: U2.12 (IO27), U3.8 (RX_EN)
/RX_EN_2: U2.30 (IO18), U5.8 (RX_EN)
/RX_ESP32: J4.3, J4.12, U2.34 (RXD0/IO3)
/SCK: J3.2, U2.10 (IO25), U3.5 (SCK_RTSN), U5.5 (SCK_RTSN)
/SDA: J3.3, U2.22 (SDI/SD1)
/SPORT: J2.2, U2.24 (IO2)
/TX: J1.3, J4.5, J4.9
/TX_EN_1: U2.13 (IO14), U3.9 (TX_EN)
/TX_EN_2: U2.16 (IO13), U5.9 (TX_EN)
/TX_ESP32: J4.1, J4.10, U2.35 (TXD0/IO1)
GND: C1.2, C2.2, C3.2, CR1.2, D1.2 (VSS), J1.5, J2.3, J3.4, J5.2, JP1.2 (B), U1.7 (GND), U1.8 (1.6V), U1.11 (0.2V), U1.12 (0.1V), U1.21 (EP), U2.1 (GND), U2.15 (GND), U2.38 (GND), U2.39 (GND), U3.2 (GND), U3.7 (GND), U3.10 (GND), U3.16 (GND), U5.2 (GND), U5.7 (GND), U5.10 (GND), U5.16 (GND); also elsewhere on the board
unnamed: C2.1, U1.14 (NR)
unnamed: R1.2, U2.3 (EN)
unnamed: R2.2, R3.2, U2.6 (IO34)

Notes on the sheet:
S.Port (CRSF)
Low-Noise RF LDO Regulator with TVS and Fuse Input Protection
Paschalis M.
Led Indicator
Flash-Program
OLED Screen
Fan
Pads, Headers and Connectors
ExpressLRS_2.4GHz_TX

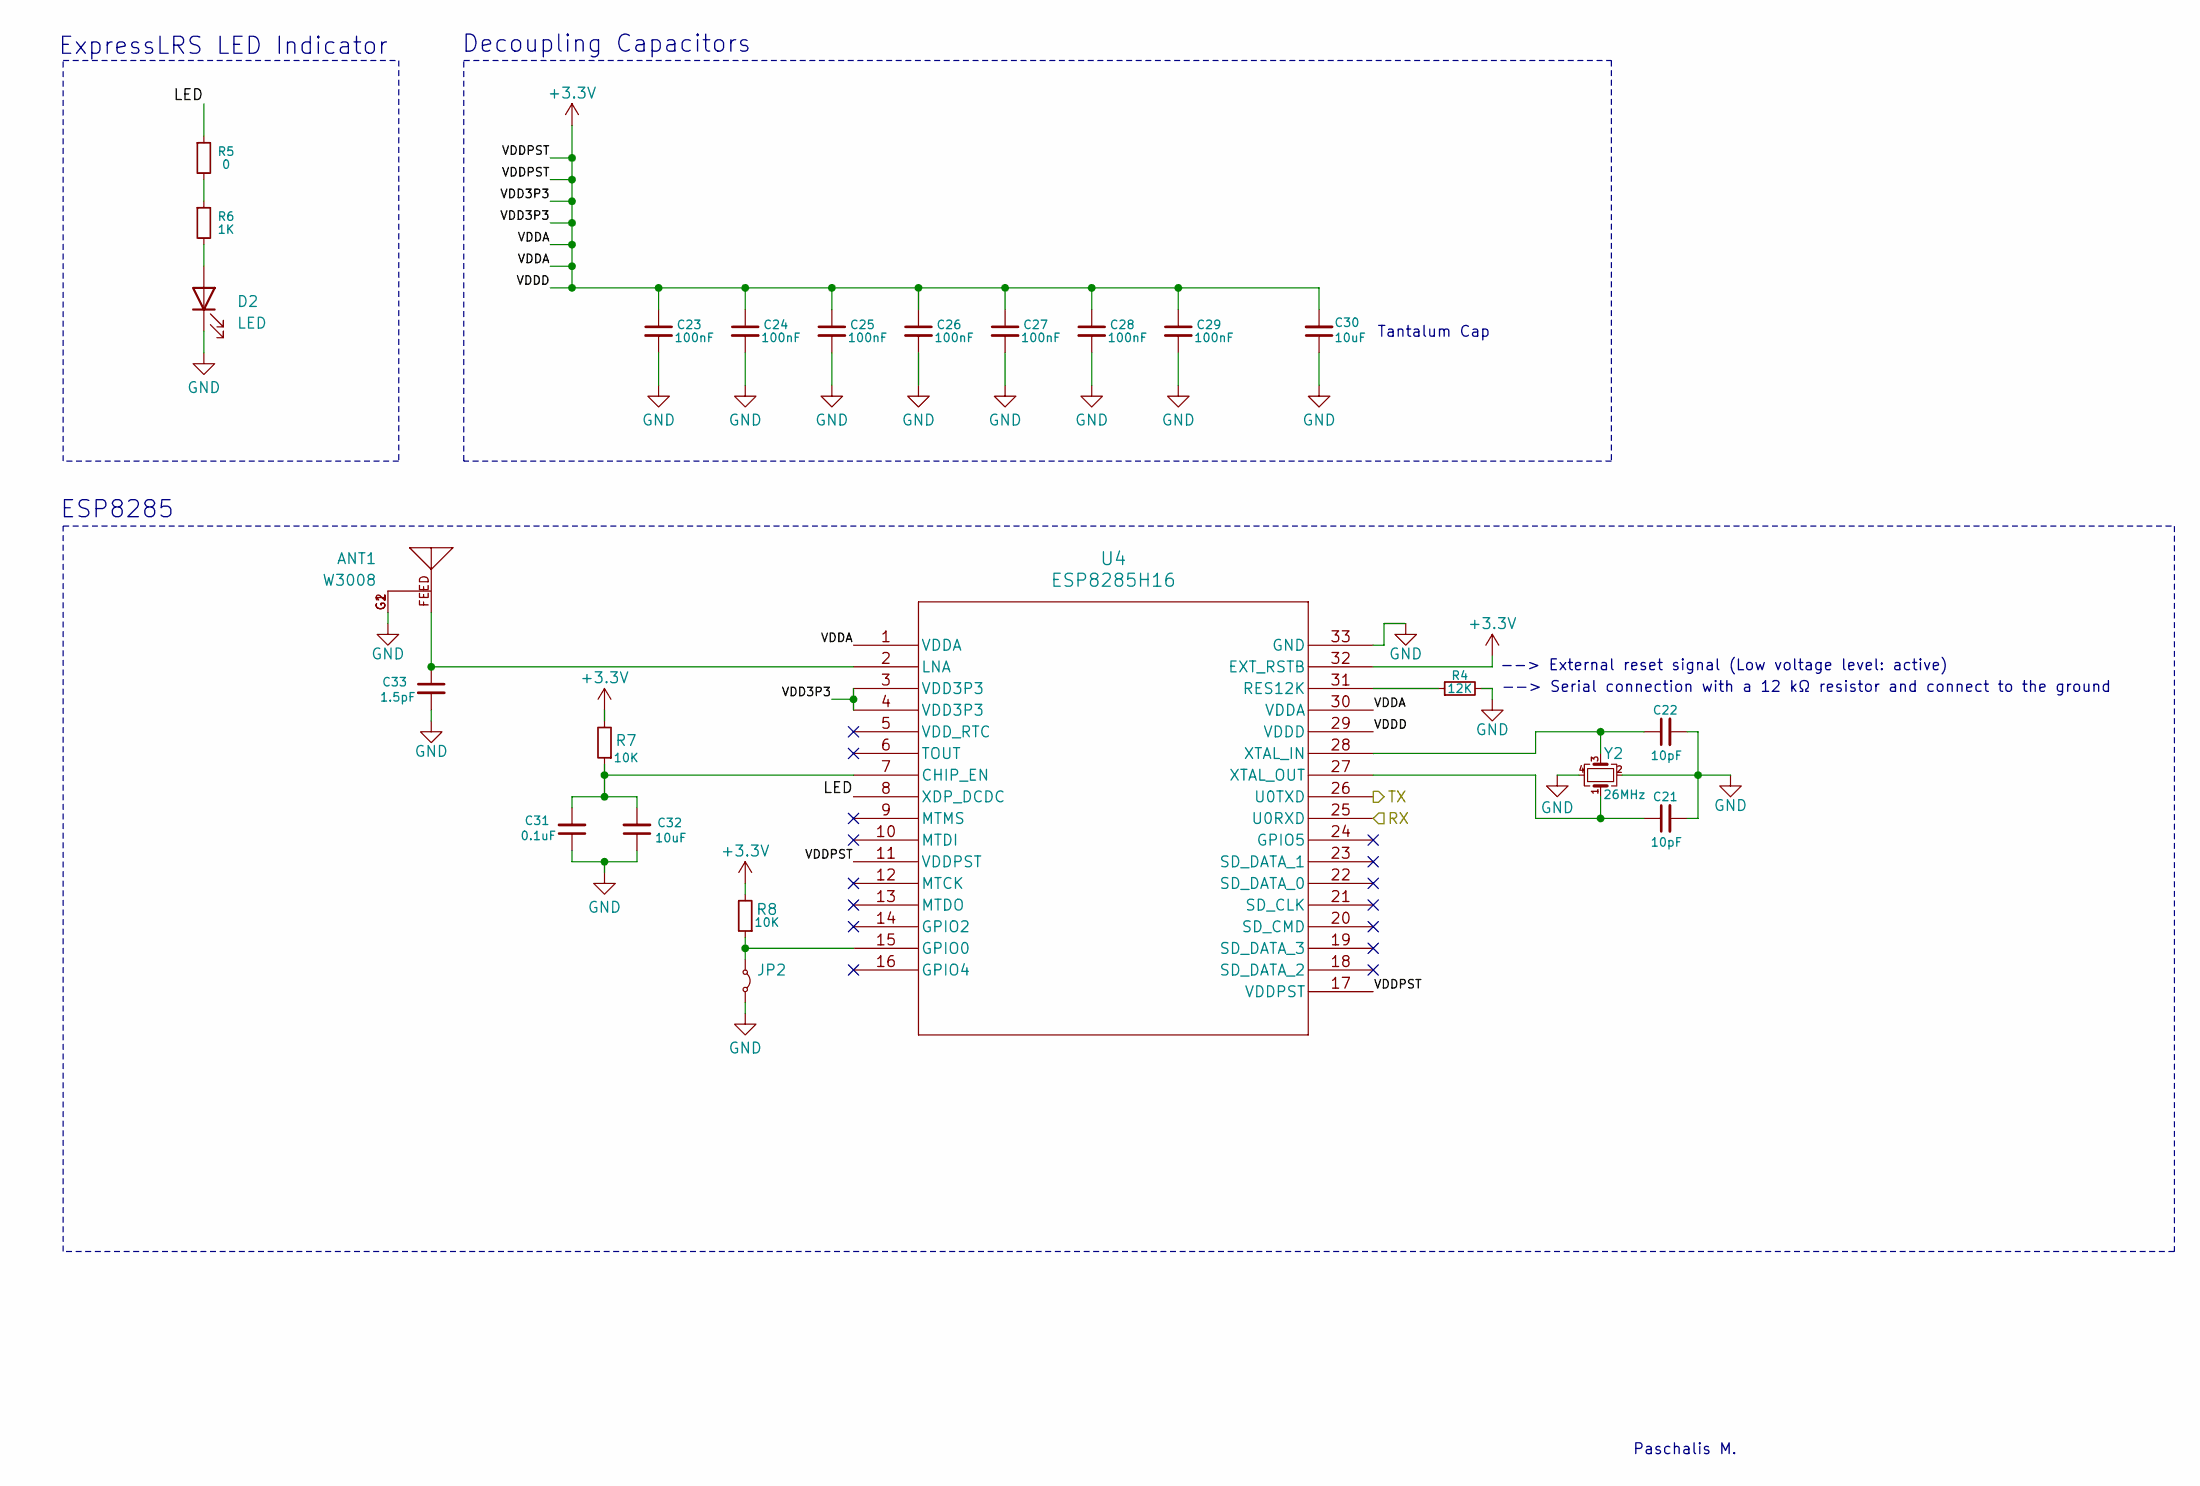
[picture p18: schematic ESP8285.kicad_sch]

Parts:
ANT1: W3008; ANTENNA_W3008
C21, C22: 10pF; C_0603_1608Metric_Pad1.08x0.95mm_HandSolder
C23, C24, C25, C26, C27, C28, C29: 100nF; C_0603_1608Metric_Pad1.08x0.95mm_HandSolder
C30, C32: 10uF; ECASD40J106M055K00
C31: 0.1uF; C_0603_1608Metric_Pad1.08x0.95mm_HandSolder
C33: 1.5pF; C_01005_0402Metric_Pad0.57x0.30mm_HandSolder
D2: LED; LED_0805_2012Metric_Pad1.15x1.40mm_HandSolder
JP2: Jumper_2_Small_Bridged; TestPoint_2Pads_Pitch2.54mm_Drill0.8mm
R4: 12K; R_0603_1608Metric_Pad0.98x0.95mm_HandSolder
R5: 0; R_0603_1608Metric_Pad0.98x0.95mm_HandSolder
R6: 1K; R_0603_1608Metric_Pad0.98x0.95mm_HandSolder
R7, R8: 10K; R_0603_1608Metric_Pad0.98x0.95mm_HandSolder
U4: ESP8285H16; QFN32_5X5_EXP
Y2: 26MHz; Crystal_SMD_2016-4Pin_2.0x1.6mm

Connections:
+3.3V: C23.1, C24.1, C25.1, C26.1, C27.1, C28.1, C29.1, C30.2, R7.2, R8.2, U4.1 (VDDA), U4.3 (VDD3P3), U4.4 (VDD3P3), U4.11 (VDDPST), U4.17 (VDDPST), U4.29 (VDDD), U4.30 (VDDA), U4.32 (EXT_RSTB); also elsewhere on the board
/ESP8285/LED: R5.1, U4.8 (XDP_DCDC)
/ESP8285/RX: U4.25 (U0RXD); also elsewhere on the board
/ESP8285/TX: U4.26 (U0TXD); also elsewhere on the board
GND: ANT1.G1, ANT1.G2, C21.2, C22.2, C23.2, C24.2, C25.2, C26.2, C27.2, C28.2, C29.2, C30.1, C31.1, C32.1, C33.2, D2.1 (K), JP2.2 (B), R4.2, U4.33 (GND), Y2.2, Y2.4; also elsewhere on the board
unnamed: D2.2 (A), R6.2
unnamed: JP2.1 (A), R8.1, U4.15 (GPIO0)
unnamed: R5.2, R6.1
unnamed: C31.2, C32.2, R7.1, U4.7 (CHIP_EN)
unnamed: ANT1.FEED, C33.1, U4.2 (LNA)
unnamed: R4.1, U4.31 (RES12K)
unnamed: C22.1, U4.28 (XTAL_IN), Y2.3
unnamed: C21.1, U4.27 (XTAL_OUT), Y2.1

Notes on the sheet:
--> External reset signal (Low voltage level: active)
--> Serial connection with a 12 kΩ resistor and connect to the ground
Decoupling Capacitors
Paschalis M.
ESP8285
Tantalum Cap
ExpressLRS LED Indicator

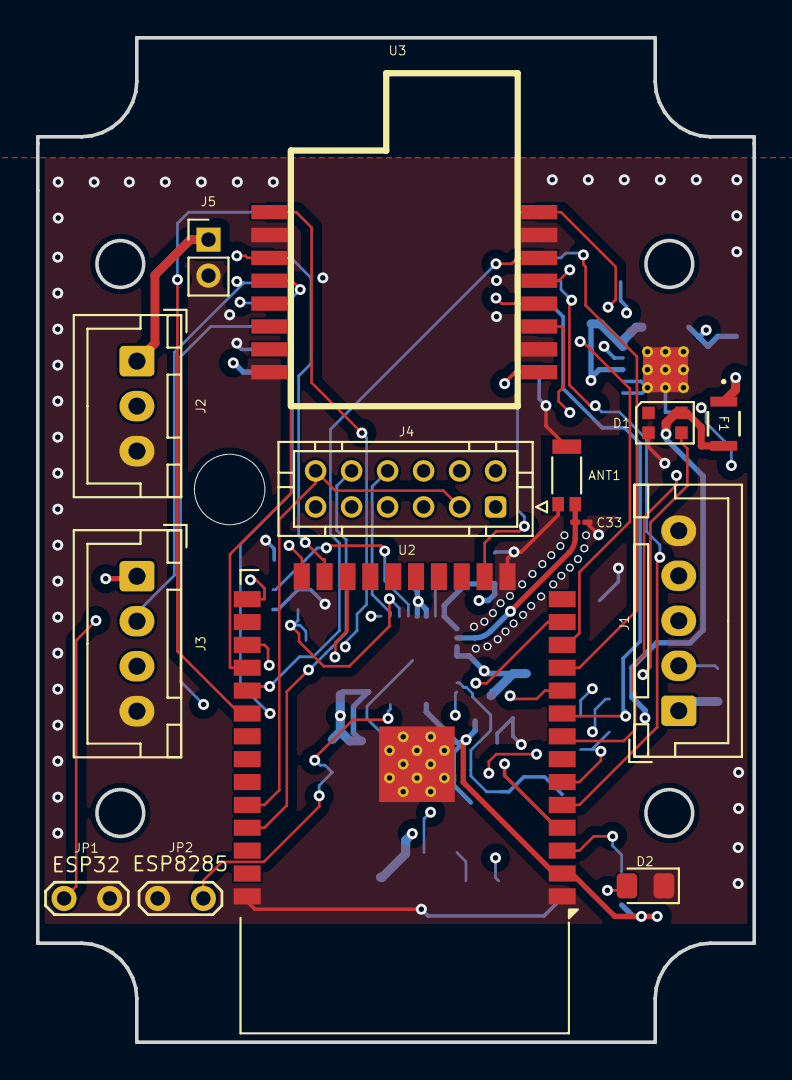
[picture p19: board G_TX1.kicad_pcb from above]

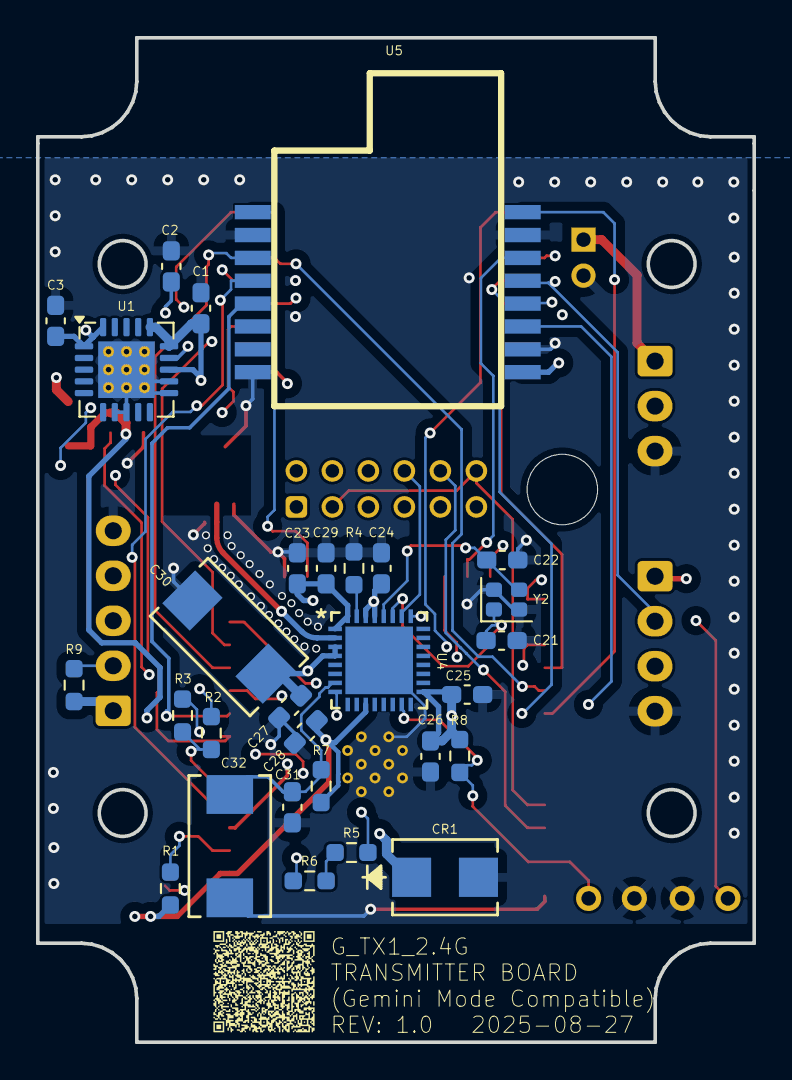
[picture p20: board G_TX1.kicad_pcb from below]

Board: 6 copper layers, 39.8 x 55.8 mm, 43 parts (29 on the bottom side), 41 nets.

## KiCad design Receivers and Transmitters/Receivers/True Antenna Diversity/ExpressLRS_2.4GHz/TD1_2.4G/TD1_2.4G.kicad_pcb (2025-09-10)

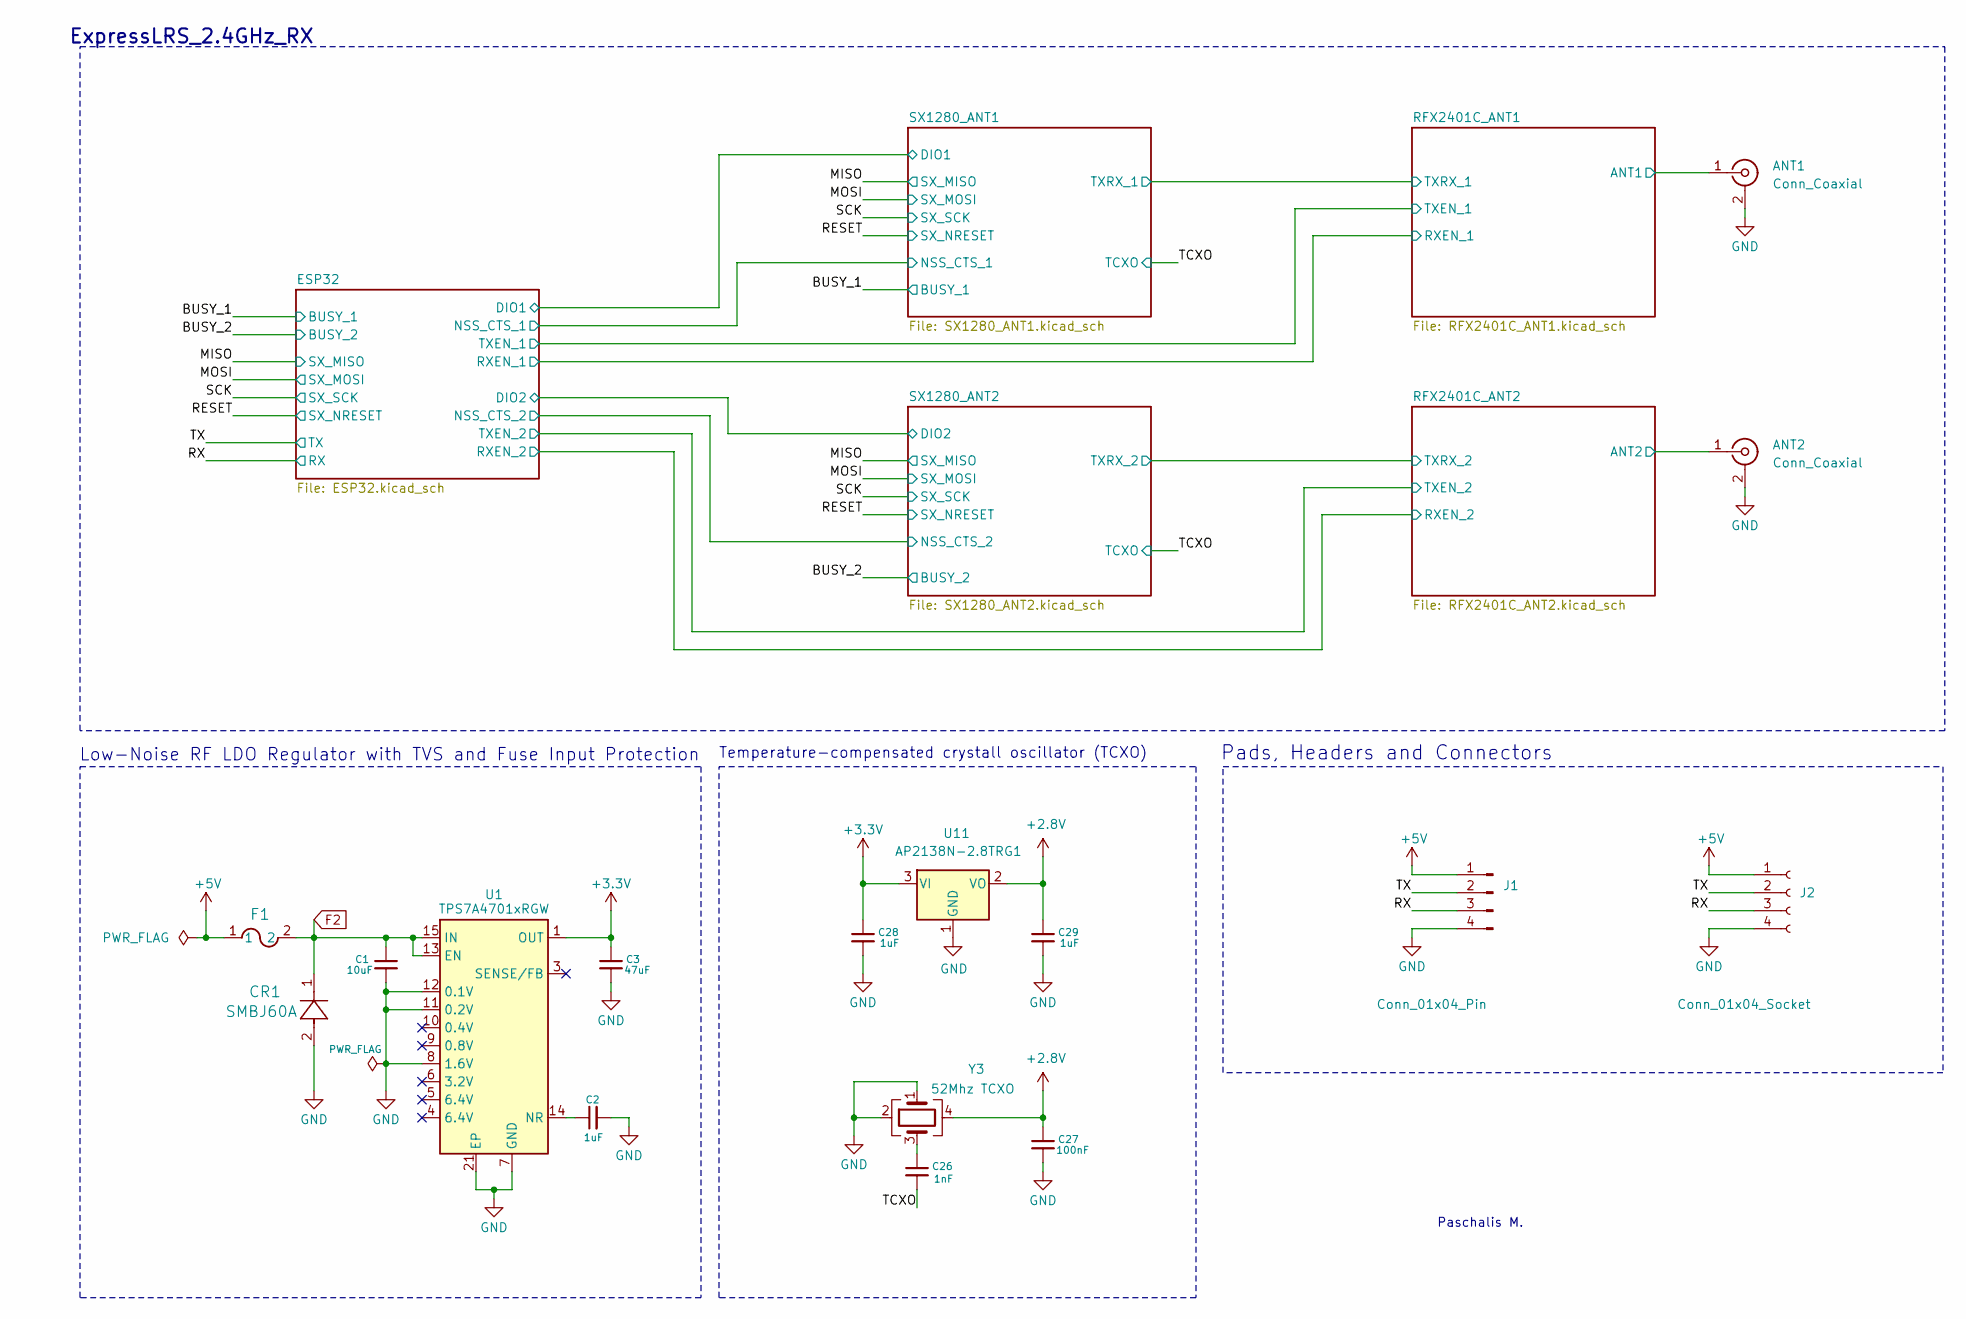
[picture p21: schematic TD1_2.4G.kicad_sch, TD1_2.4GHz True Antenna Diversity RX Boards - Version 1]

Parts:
ANT1, ANT2: Conn_Coaxial; U.FL_Hirose_U.FL-R-SMT-1_Vertical
C1: 10uF; C_0603_1608Metric_Pad1.08x0.95mm_HandSolder
C2, C28, C29: 1uF; C_0603_1608Metric_Pad1.08x0.95mm_HandSolder
C3: 47uF; C_0603_1608Metric_Pad1.08x0.95mm_HandSolder
C26: 1nF; C_0603_1608Metric_Pad1.08x0.95mm_HandSolder
C27: 100nF; C_0603_1608Metric_Pad1.08x0.95mm_HandSolder
CR1: SMBJ60A; SMBJSeries_LTF
F1: MF-PSMF020X-2; FUSE_F020X_BRN
J1: Conn_01x04_Pin; JST_GH_SM04B-GHS-TB_1x04-1MP_P1.25mm_Horizontal
J2: Conn_01x04_Socket; Harwin_M20-89004xx_1x04_P2.54mm_Horizontal
U1: TPS7A4701xRGW; Texas_RGW0020A_VQFN-20-1EP_5x5mm_P0.65mm_EP3.15x3.15mm_Ther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
U11: AP2138N-2.8TRG1; SOT-23; LCSC C176956
Y3: 52Mhz TCXO; Crystal_SMD_2016-4Pin_2.0x1.6mm; Digikey 2151-RTX-2016BD32-S-52.000-TR-NS1TR-ND

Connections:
+2.8V: C27.1, C29.1, U11.2 (VO), Y3.4
+3.3V: C3.1, C28.1, U1.1 (OUT), U1.20 (OUT), U11.3 (VI); also elsewhere on the board
+5V: F1.1, J1.1, J2.1
/RFX2401C_ANT1/ANT1: ANT1.1 (In); also elsewhere on the board
/RFX2401C_ANT2/ANT2: ANT2.1 (In); also elsewhere on the board
/RX: J1.3, J2.3; also elsewhere on the board
/TCXO: C26.2; also elsewhere on the board
/TX: J1.2, J2.2; also elsewhere on the board
F2: C1.1, CR1.1, F1.2, U1.13 (EN), U1.15 (IN), U1.16 (IN); also elsewhere on the board
GND: ANT1.2 (Ext), ANT2.2 (Ext), C1.2, C2.2, C3.2, C27.2, C28.2, C29.2, CR1.2, J1.4, J2.4, U1.7 (GND), U1.8 (1.6V), U1.11 (0.2V), U1.12 (0.1V), U1.21 (EP), U11.1 (GND), Y3.1, Y3.2; also elsewhere on the board
unnamed: C26.1, Y3.3
unnamed: C2.1, U1.14 (NR)

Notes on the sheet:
Temperature-compensated crystall oscillator (TCXO)
Low-Noise RF LDO Regulator with TVS and Fuse Input Protection
Pads, Headers and Connectors
ExpressLRS_2.4GHz_RX
Paschalis M.

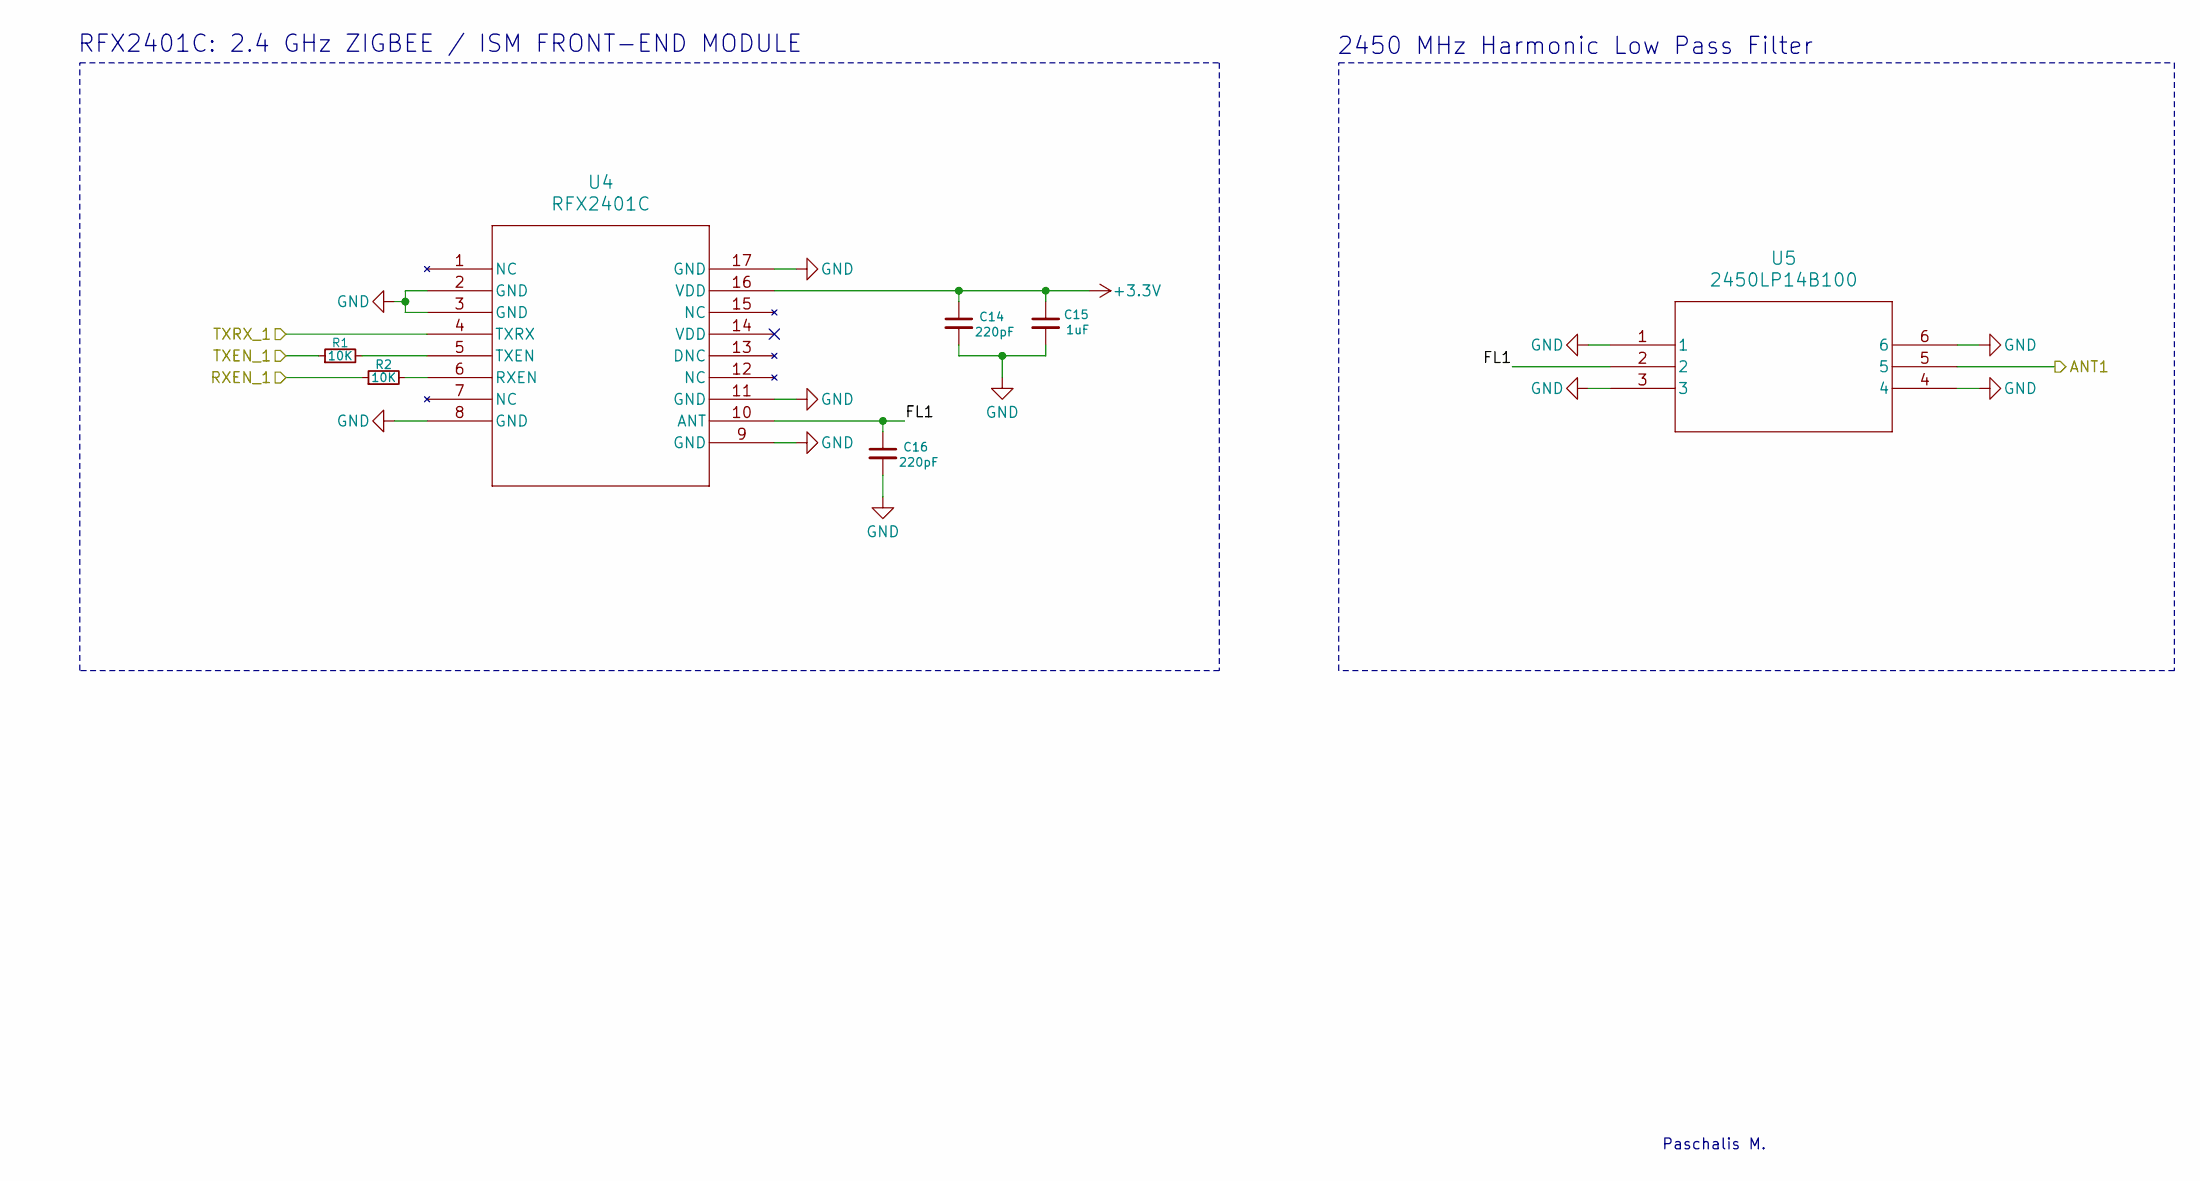
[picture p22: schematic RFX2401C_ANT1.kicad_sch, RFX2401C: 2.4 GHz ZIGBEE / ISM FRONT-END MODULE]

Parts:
C14, C16: 220pF; C_0603_1608Metric_Pad1.08x0.95mm_HandSolder
C15: 1uF; C_0603_1608Metric_Pad1.08x0.95mm_HandSolder
R1, R2: 10K; R_0603_1608Metric_Pad0.98x0.95mm_HandSolder
U4: RFX2401C; RFX2401C_SKY
U5: 2450LP14B100; CHIP_SMD_1P6XP8_JOD

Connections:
+3.3V: C14.1, C15.1, U4.16 (VDD); also elsewhere on the board
/ESP32/RXEN_1: R2.1; also elsewhere on the board
/ESP32/TXEN_1: R1.1; also elsewhere on the board
/RFX2401C_ANT1/ANT1: U5.5; also elsewhere on the board
/RFX2401C_ANT1/FL1: C16.1, U4.10 (ANT), U5.2
/RFX2401C_ANT1/TXRX_1: U4.4 (TXRX); also elsewhere on the board
GND: C14.2, C15.2, C16.2, U4.2 (GND), U4.3 (GND), U4.8 (GND), U4.9 (GND), U4.11 (GND), U4.17 (GND), U5.1, U5.3, U5.4, U5.6; also elsewhere on the board
unnamed: R2.2, U4.6 (RXEN)
unnamed: R1.2, U4.5 (TXEN)

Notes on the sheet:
RFX2401C: 2.4 GHz ZIGBEE / ISM FRONT-END MODULE
Paschalis M.
2450 MHz Harmonic Low Pass Filter

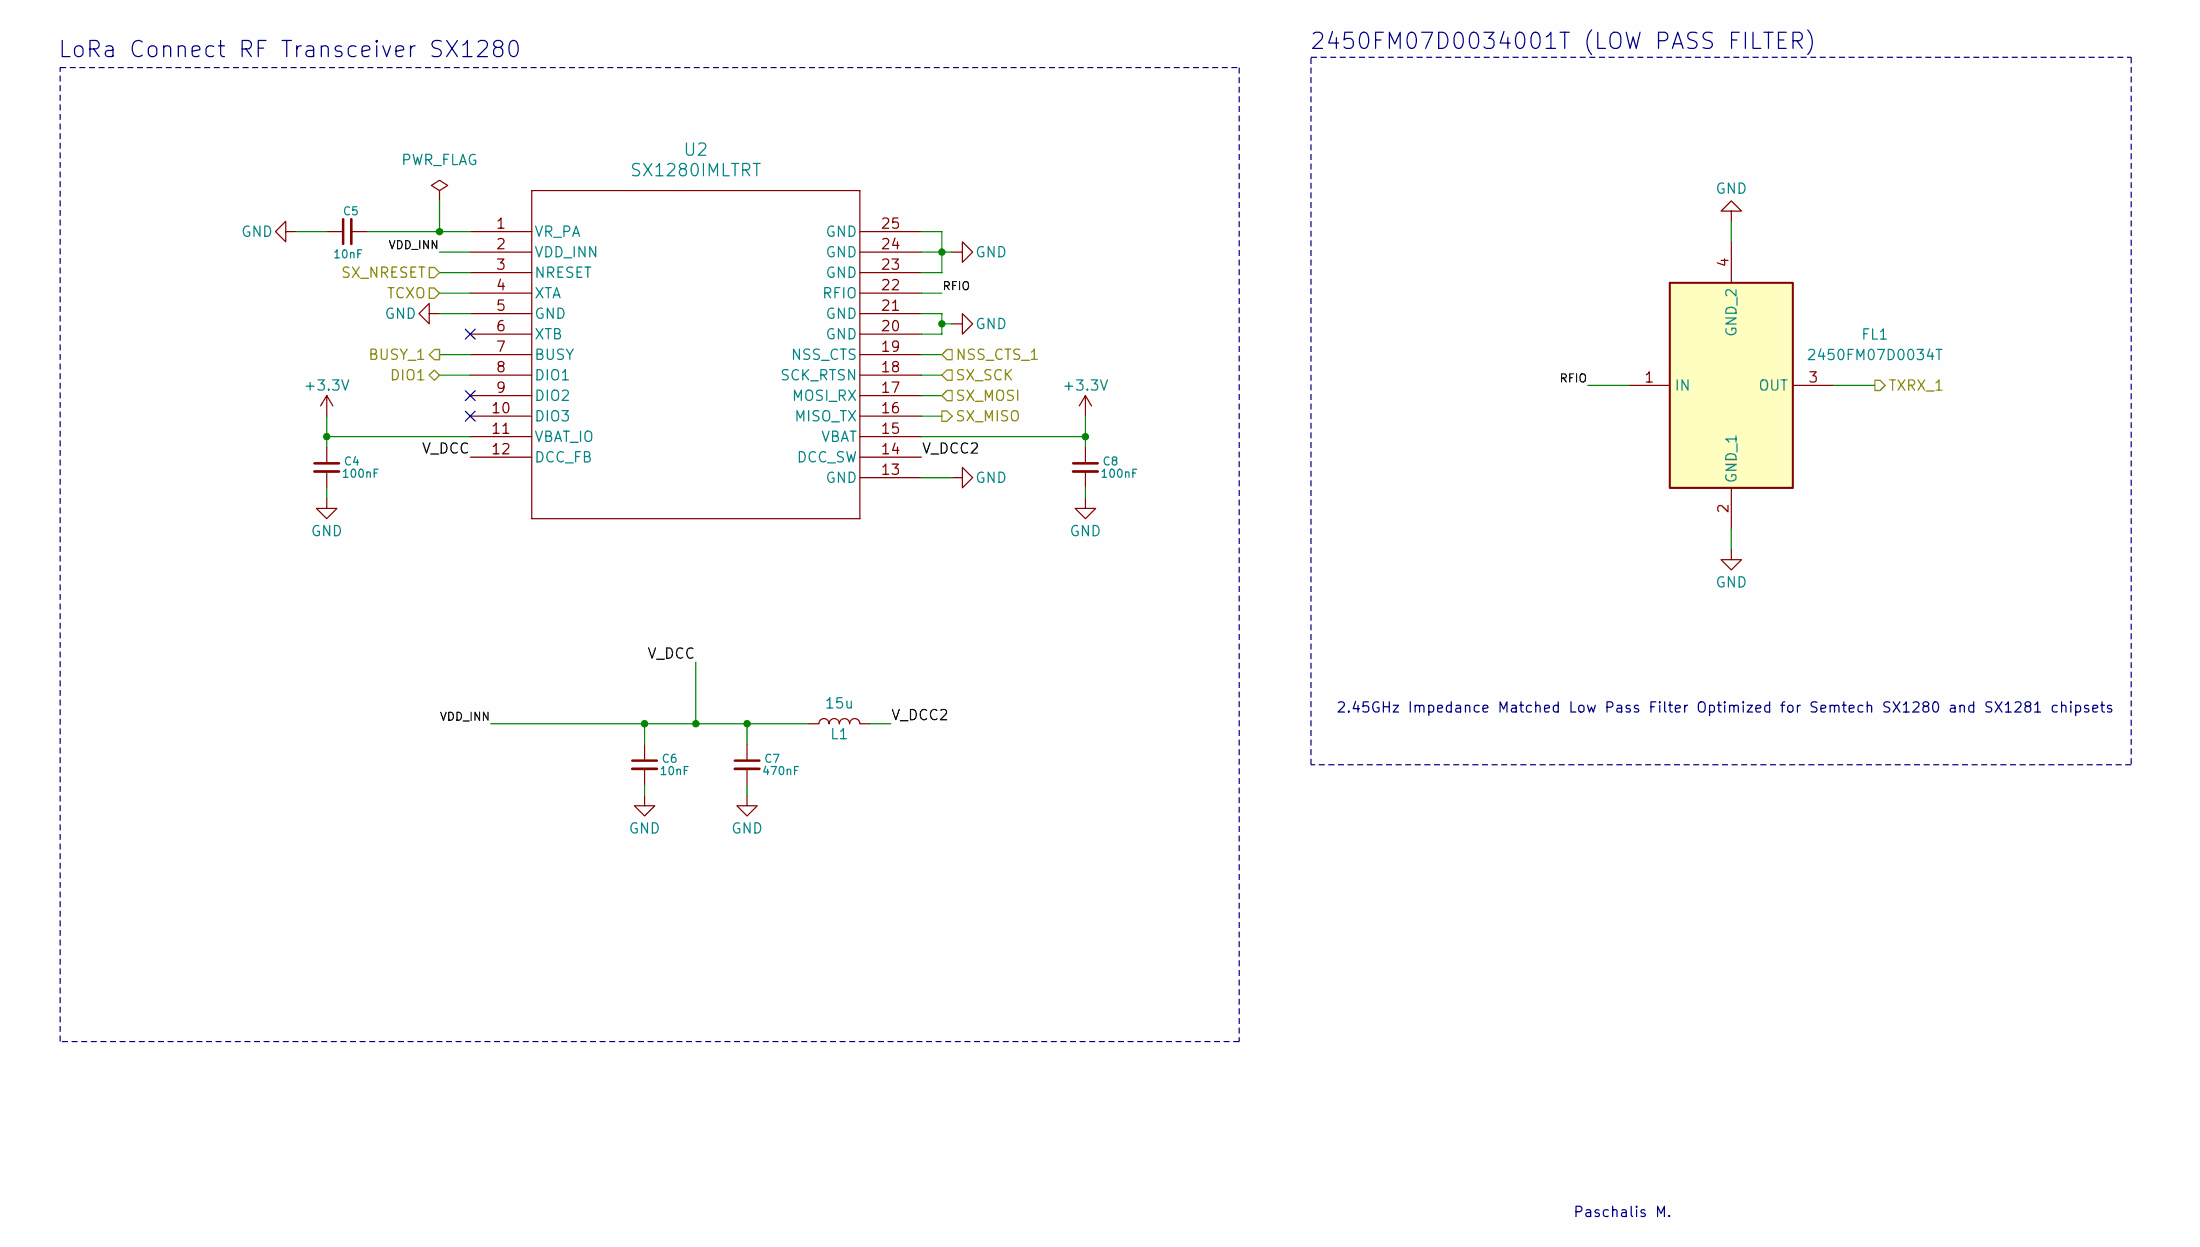
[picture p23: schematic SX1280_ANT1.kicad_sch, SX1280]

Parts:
C4, C8: 100nF; C_0603_1608Metric_Pad1.08x0.95mm_HandSolder
C5, C6: 10nF; C_0603_1608Metric_Pad1.08x0.95mm_HandSolder
C7: 470nF; C_0603_1608Metric_Pad1.08x0.95mm_HandSolder
FL1: 2450FM07D0034T; Mouser Part Number 609-2450FM07D0034T
L1: 15u; L_0805_2012Metric; LCSC C486333
U2: SX1280IMLTRT; QFN24_4X4_SEM

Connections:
+3.3V: C4.1, C8.1, U2.11 (VBAT_IO), U2.15 (VBAT); also elsewhere on the board
/BUSY_1: U2.7 (BUSY); also elsewhere on the board
/ESP32/DIO1: U2.8 (DIO1); also elsewhere on the board
/ESP32/NSS_CTS_1: U2.19 (NSS_CTS); also elsewhere on the board
/MISO: U2.16 (MISO_TX); also elsewhere on the board
/MOSI: U2.17 (MOSI_RX); also elsewhere on the board
/RESET: U2.3 (NRESET); also elsewhere on the board
/RFX2401C_ANT1/TXRX_1: FL1.3 (OUT); also elsewhere on the board
/SCK: U2.18 (SCK_RTSN); also elsewhere on the board
/SX1280_ANT1/RFIO: FL1.1 (IN), U2.22 (RFIO)
/SX1280_ANT1/VDD_INN: C6.1, C7.1, L1.1, U2.2 (VDD_INN), U2.12 (DCC_FB)
/SX1280_ANT1/V_DCC2: L1.2, U2.14 (DCC_SW)
/TCXO: U2.4 (XTA); also elsewhere on the board
GND: C4.2, C5.1, C6.2, C7.2, C8.2, FL1.2 (GND_1), FL1.4 (GND_2), U2.5 (GND), U2.13 (GND), U2.20 (GND), U2.21 (GND), U2.23 (GND), U2.24 (GND), U2.25 (GND); also elsewhere on the board
unnamed: C5.2, U2.1 (VR_PA)

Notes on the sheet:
LoRa Connect RF Transceiver SX1280
Paschalis M.
2.45GHz Impedance Matched Low Pass Filter Optimized for Semtech SX1280 and SX1281 chipsets
2450FM07D0034001T (LOW PASS FILTER)

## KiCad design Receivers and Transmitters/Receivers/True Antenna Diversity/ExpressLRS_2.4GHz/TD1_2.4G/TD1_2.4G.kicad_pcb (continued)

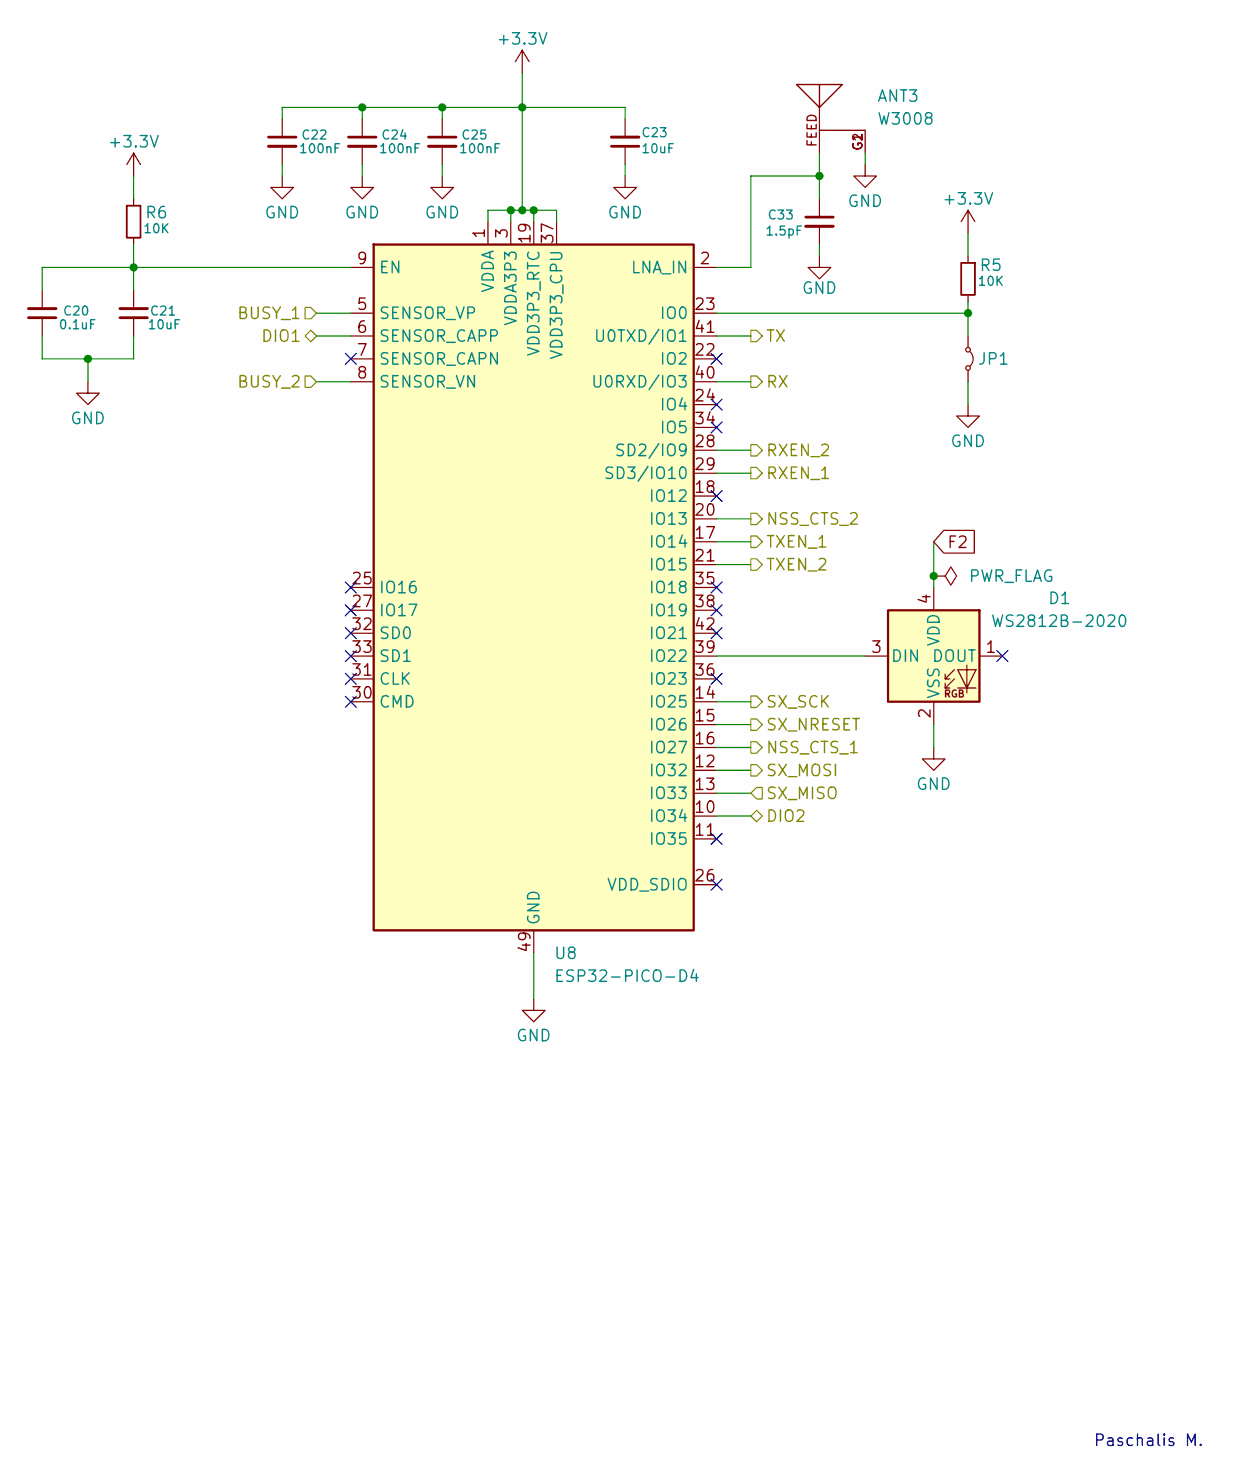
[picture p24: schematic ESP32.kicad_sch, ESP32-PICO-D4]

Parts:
ANT3: W3008; ANTENNA_W3008
C20: 0.1uF; C_0603_1608Metric_Pad1.08x0.95mm_HandSolder
C21, C23: 10uF; ECASD40J106M055K00
C22, C24, C25: 100nF; C_0603_1608Metric_Pad1.08x0.95mm_HandSolder
C33: 1.5pF; C_01005_0402Metric_Pad0.57x0.30mm_HandSolder
D1: WS2812B-2020; LED_WS2812B-2020_PLCC4_2.0x2.0mm
JP1: Jumper_2_Small_Bridged; TestPoint_2Pads_Pitch2.54mm_Drill0.8mm
R5, R6: 10K; R_0603_1608Metric_Pad0.98x0.95mm_HandSolder
U8: ESP32-PICO-D4; QFN-48-1EP_7x7mm_P0.5mm_EP5.1x5.1mm_ThermalVias

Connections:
+3.3V: C22.1, C23.2, C24.1, C25.1, R5.1, R6.1, U8.1 (VDDA), U8.3 (VDDA3P3), U8.4 (VDDA3P3), U8.19 (VDD3P3_RTC), U8.37 (VDD3P3_CPU), U8.43 (VDDA), U8.46 (VDDA); also elsewhere on the board
/BUSY_1: U8.5 (SENSOR_VP); also elsewhere on the board
/BUSY_2: U8.8 (SENSOR_VN); also elsewhere on the board
/ESP32/DIO1: U8.6 (SENSOR_CAPP); also elsewhere on the board
/ESP32/DIO2: U8.10 (IO34); also elsewhere on the board
/ESP32/NSS_CTS_1: U8.16 (IO27); also elsewhere on the board
/ESP32/NSS_CTS_2: U8.20 (IO13); also elsewhere on the board
/ESP32/RXEN_1: U8.29 (SD3/IO10); also elsewhere on the board
/ESP32/RXEN_2: U8.28 (SD2/IO9); also elsewhere on the board
/ESP32/TXEN_1: U8.17 (IO14); also elsewhere on the board
/ESP32/TXEN_2: U8.21 (IO15); also elsewhere on the board
/MISO: U8.13 (IO33); also elsewhere on the board
/MOSI: U8.12 (IO32); also elsewhere on the board
/RESET: U8.15 (IO26); also elsewhere on the board
/RX: U8.40 (U0RXD/IO3); also elsewhere on the board
/SCK: U8.14 (IO25); also elsewhere on the board
/TX: U8.41 (U0TXD/IO1); also elsewhere on the board
F2: D1.4 (VDD); also elsewhere on the board
GND: ANT3.G1, ANT3.G2, C20.1, C21.1, C22.2, C23.1, C24.2, C25.2, C33.2, D1.2 (VSS), JP1.2 (B), U8.49 (GND); also elsewhere on the board
unnamed: D1.3 (DIN), U8.39 (IO22)
unnamed: JP1.1 (A), R5.2, U8.23 (IO0)
unnamed: C20.2, C21.2, R6.2, U8.9 (EN)
unnamed: ANT3.FEED, C33.1, U8.2 (LNA_IN)

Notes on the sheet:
Paschalis M.

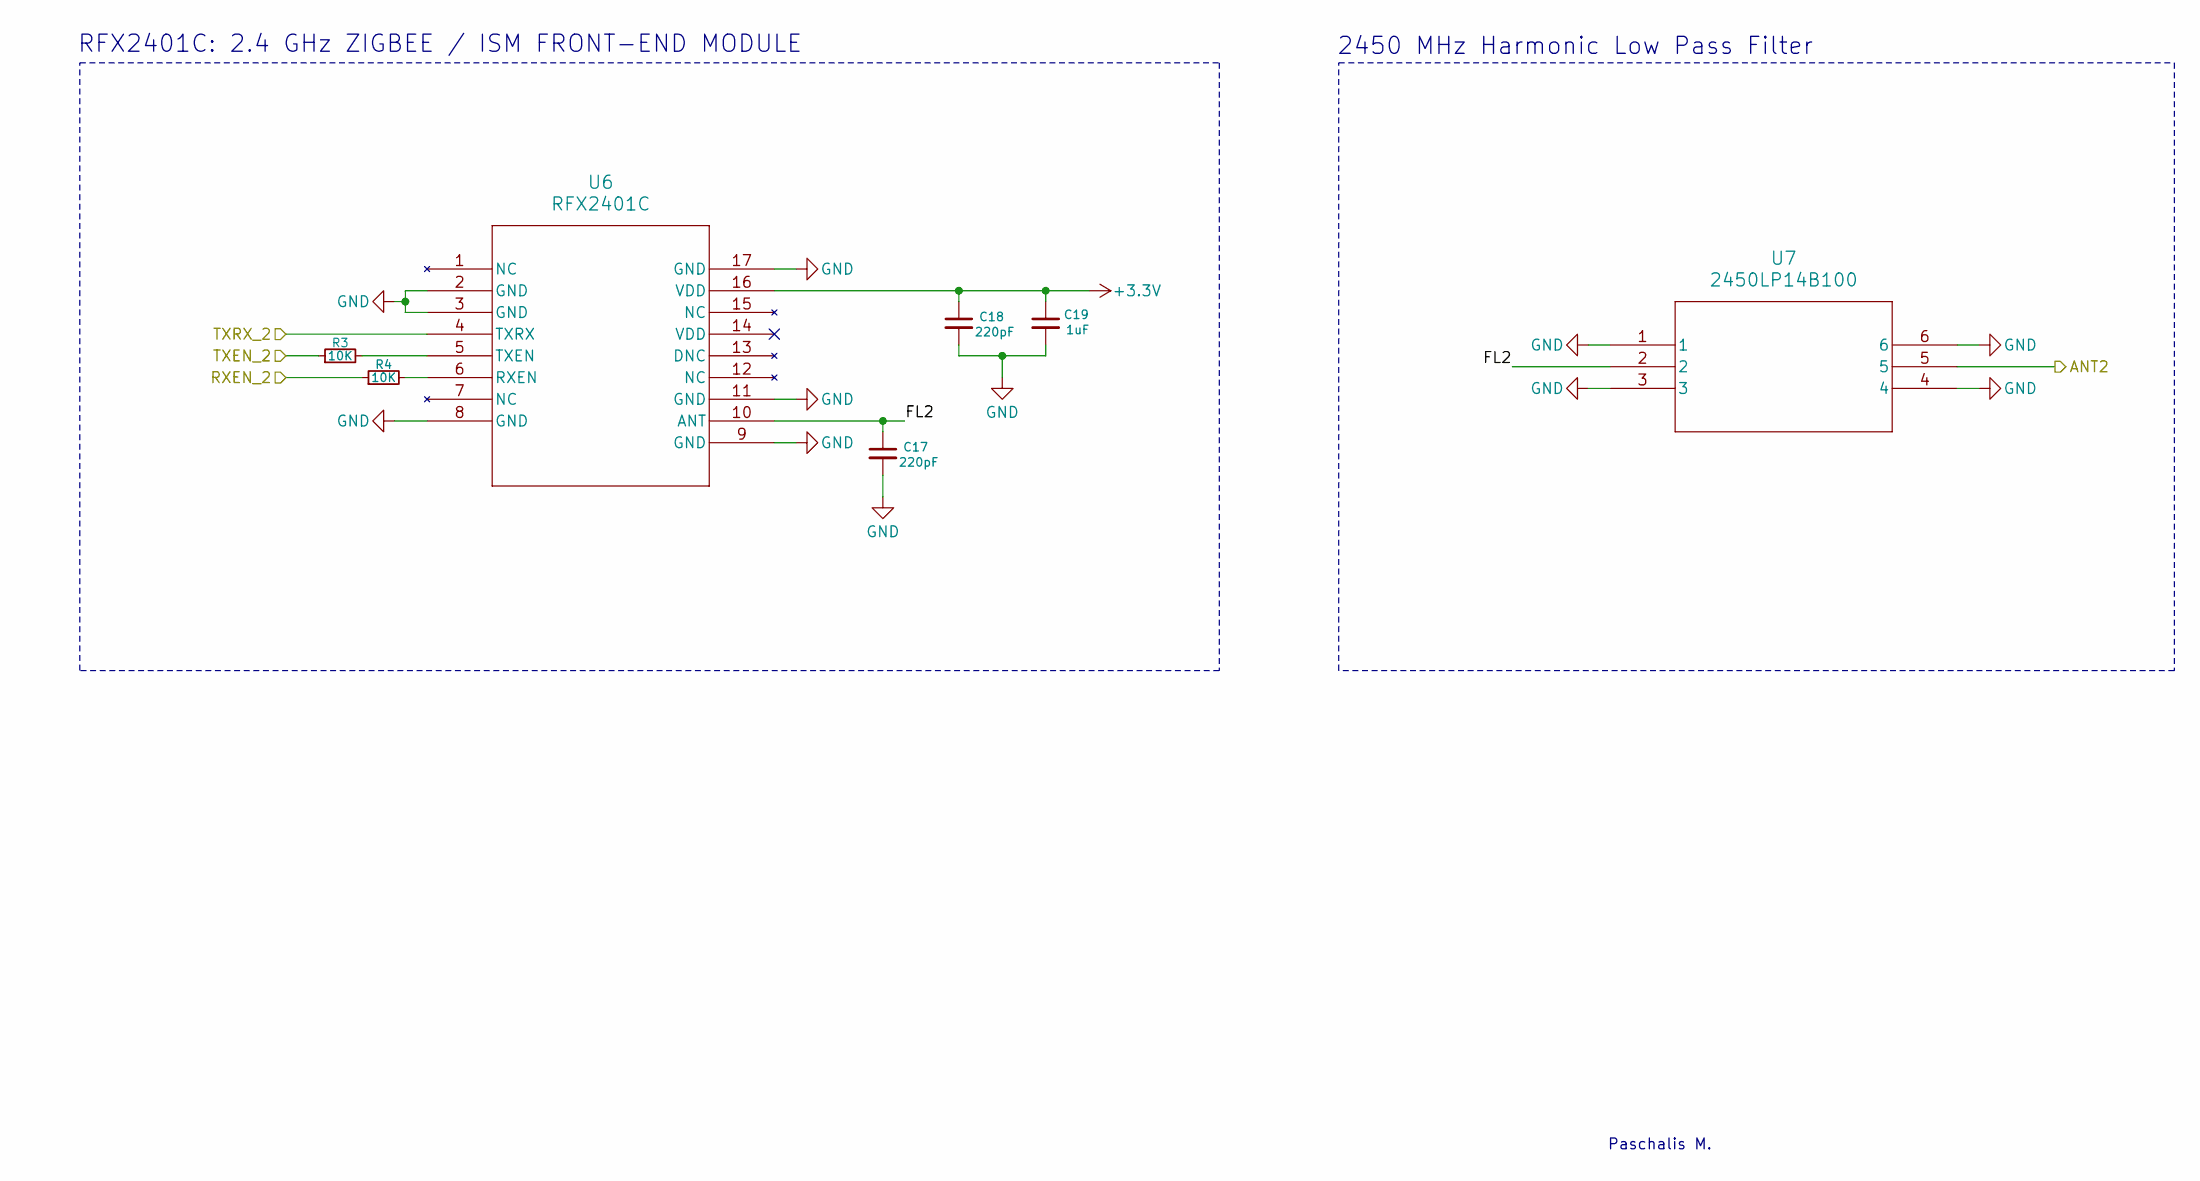
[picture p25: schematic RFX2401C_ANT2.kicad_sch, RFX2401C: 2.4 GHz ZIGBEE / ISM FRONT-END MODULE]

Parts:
C17, C18: 220pF; C_0603_1608Metric_Pad1.08x0.95mm_HandSolder
C19: 1uF; C_0603_1608Metric_Pad1.08x0.95mm_HandSolder
R3, R4: 10K; R_0603_1608Metric_Pad0.98x0.95mm_HandSolder
U6: RFX2401C; RFX2401C_SKY
U7: 2450LP14B100; CHIP_SMD_1P6XP8_JOD

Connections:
+3.3V: C18.1, C19.1, U6.16 (VDD); also elsewhere on the board
/ESP32/RXEN_2: R4.1; also elsewhere on the board
/ESP32/TXEN_2: R3.1; also elsewhere on the board
/RFX2401C_ANT2/ANT2: U7.5; also elsewhere on the board
/RFX2401C_ANT2/FL2: C17.1, U6.10 (ANT), U7.2
/RFX2401C_ANT2/TXRX_2: U6.4 (TXRX); also elsewhere on the board
GND: C17.2, C18.2, C19.2, U6.2 (GND), U6.3 (GND), U6.8 (GND), U6.9 (GND), U6.11 (GND), U6.17 (GND), U7.1, U7.3, U7.4, U7.6; also elsewhere on the board
unnamed: R4.2, U6.6 (RXEN)
unnamed: R3.2, U6.5 (TXEN)

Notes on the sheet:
RFX2401C: 2.4 GHz ZIGBEE / ISM FRONT-END MODULE
Paschalis M.
2450 MHz Harmonic Low Pass Filter

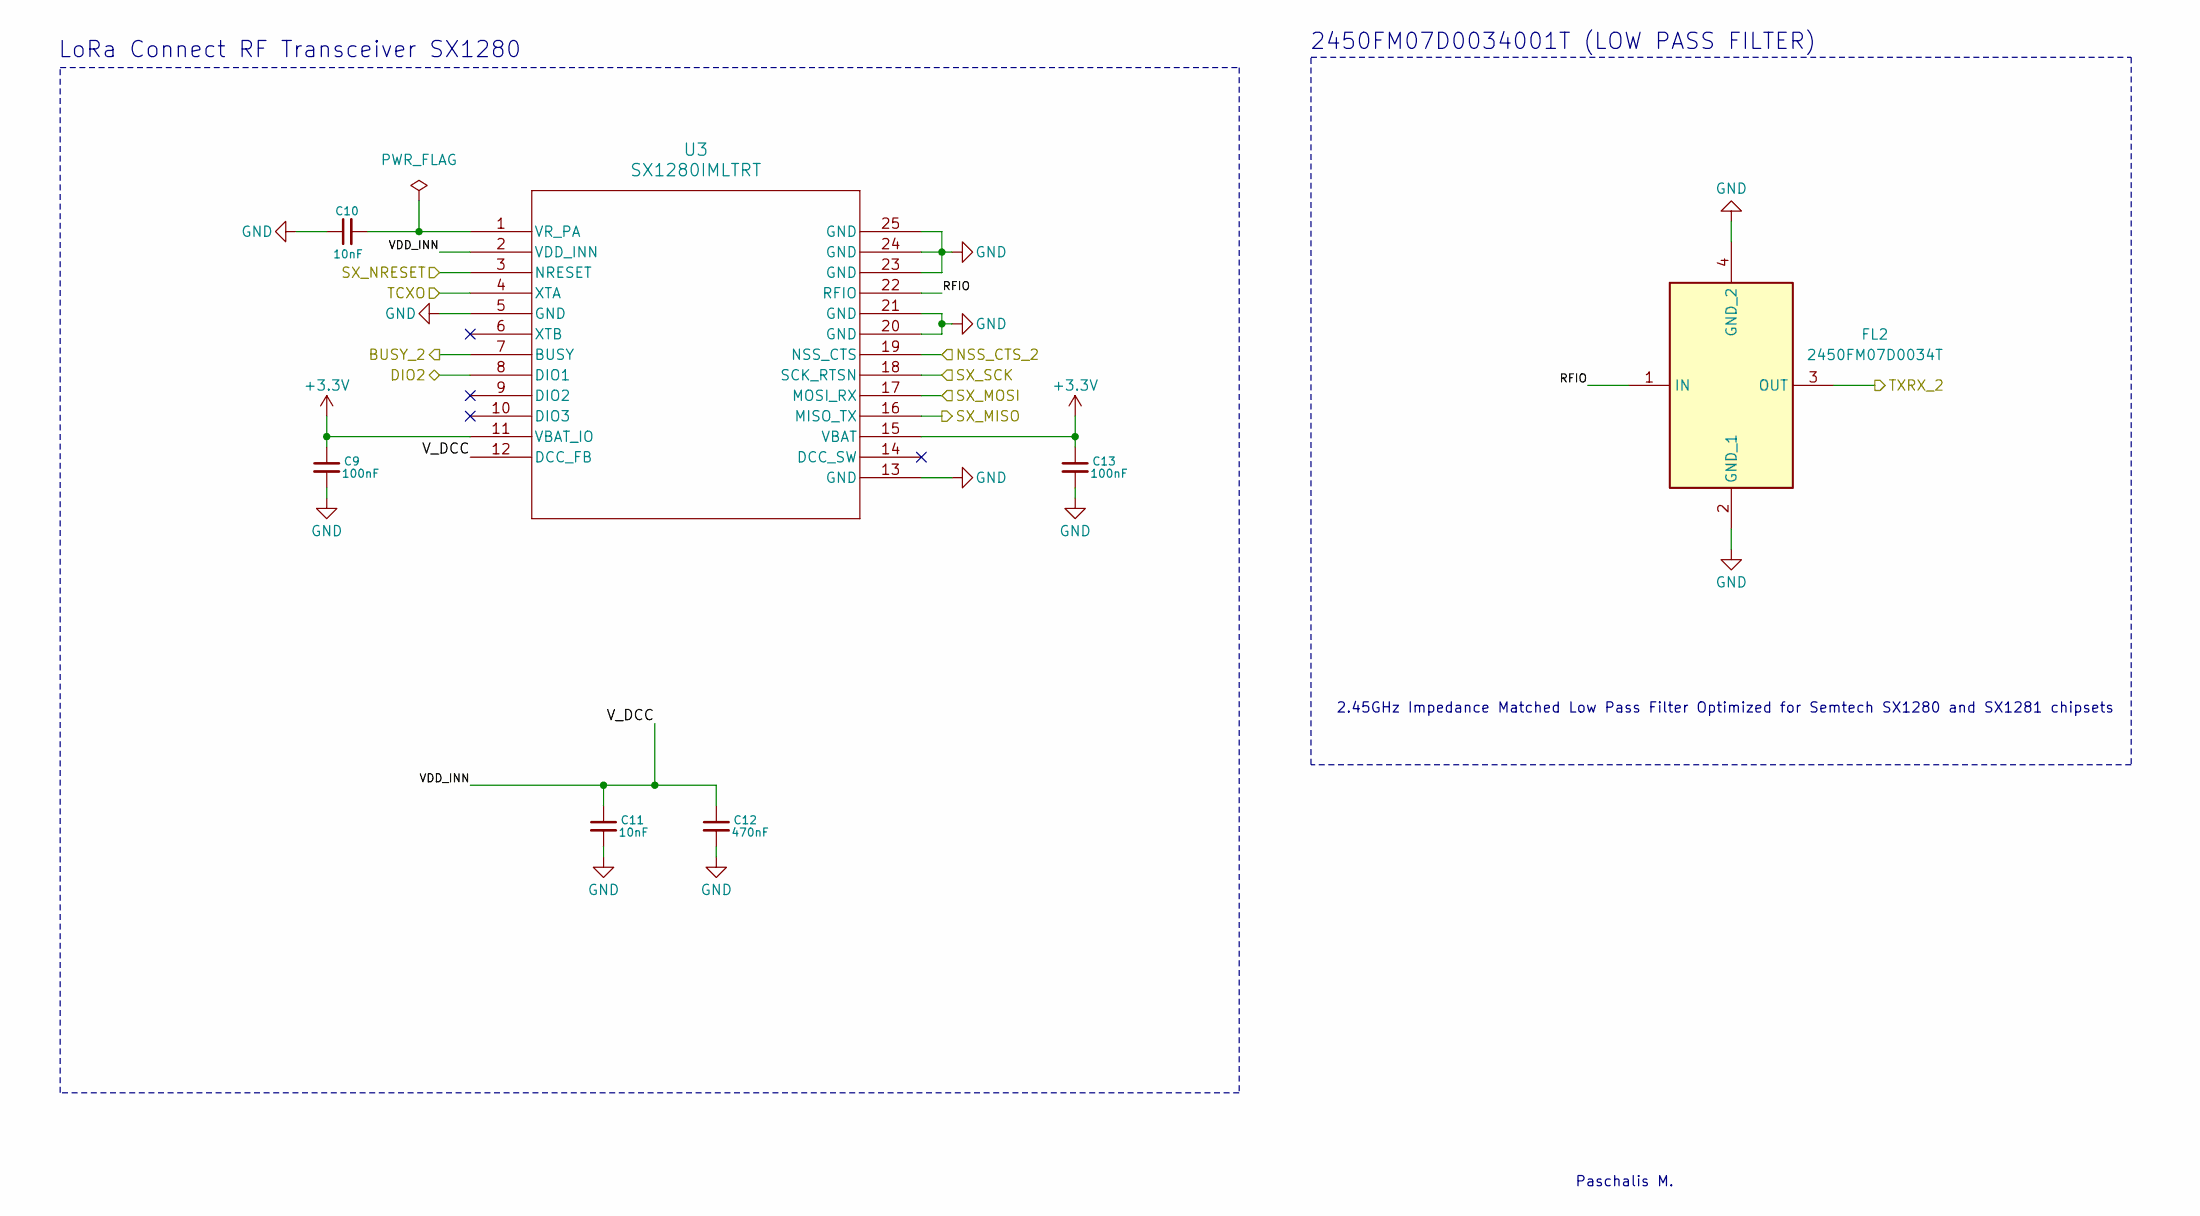
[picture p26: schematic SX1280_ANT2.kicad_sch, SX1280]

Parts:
C9, C13: 100nF; C_0603_1608Metric_Pad1.08x0.95mm_HandSolder
C10, C11: 10nF; C_0603_1608Metric_Pad1.08x0.95mm_HandSolder
C12: 470nF; C_0603_1608Metric_Pad1.08x0.95mm_HandSolder
FL2: 2450FM07D0034T; Mouser Part Number 609-2450FM07D0034T
U3: SX1280IMLTRT; QFN24_4X4_SEM

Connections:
+3.3V: C9.1, C13.1, U3.11 (VBAT_IO), U3.15 (VBAT); also elsewhere on the board
/BUSY_2: U3.7 (BUSY); also elsewhere on the board
/ESP32/DIO2: U3.8 (DIO1); also elsewhere on the board
/ESP32/NSS_CTS_2: U3.19 (NSS_CTS); also elsewhere on the board
/MISO: U3.16 (MISO_TX); also elsewhere on the board
/MOSI: U3.17 (MOSI_RX); also elsewhere on the board
/RESET: U3.3 (NRESET); also elsewhere on the board
/RFX2401C_ANT2/TXRX_2: FL2.3 (OUT); also elsewhere on the board
/SCK: U3.18 (SCK_RTSN); also elsewhere on the board
/SX1280_ANT2/RFIO: FL2.1 (IN), U3.22 (RFIO)
/SX1280_ANT2/VDD_INN: C11.1, C12.1, U3.2 (VDD_INN), U3.12 (DCC_FB)
/TCXO: U3.4 (XTA); also elsewhere on the board
GND: C9.2, C10.1, C11.2, C12.2, C13.2, FL2.2 (GND_1), FL2.4 (GND_2), U3.5 (GND), U3.13 (GND), U3.20 (GND), U3.21 (GND), U3.23 (GND), U3.24 (GND), U3.25 (GND); also elsewhere on the board
unnamed: C10.2, U3.1 (VR_PA)

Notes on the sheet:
LoRa Connect RF Transceiver SX1280
Paschalis M.
2450FM07D0034001T (LOW PASS FILTER)
2.45GHz Impedance Matched Low Pass Filter Optimized for Semtech SX1280 and SX1281 chipsets

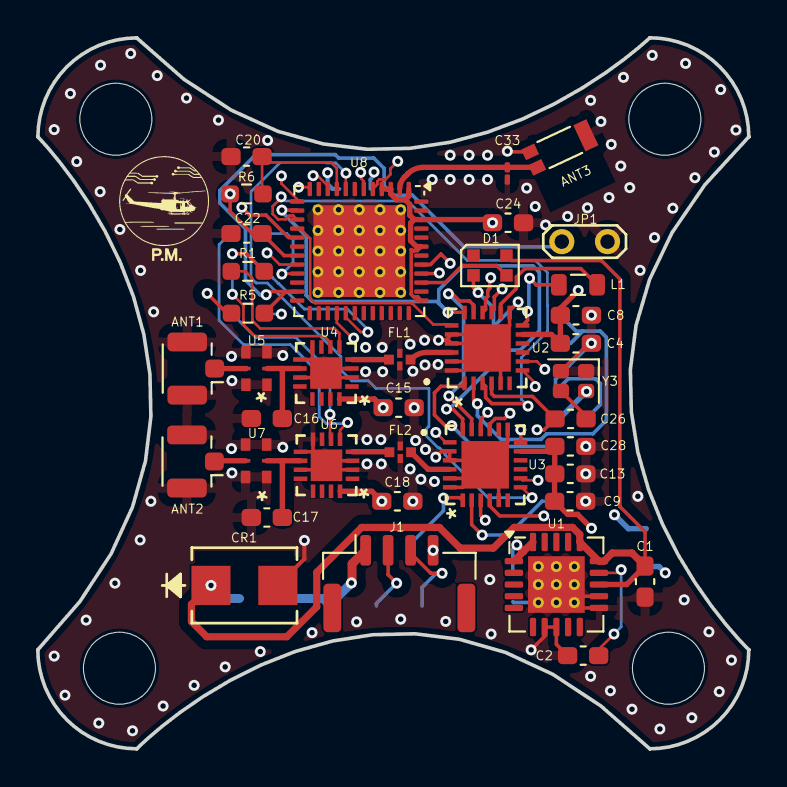
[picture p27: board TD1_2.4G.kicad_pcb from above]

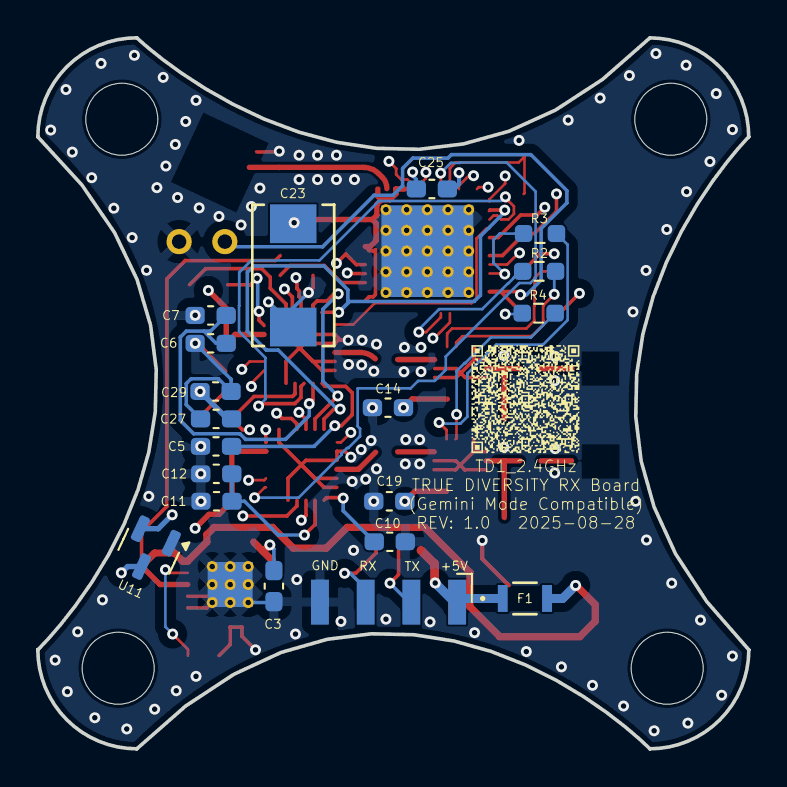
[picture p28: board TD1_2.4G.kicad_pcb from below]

Board: 6 copper layers, 39.5 x 39.5 mm, 61 parts (19 on the bottom side), 45 nets.

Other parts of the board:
Hole3, Hole4: (no value)
hole1, hole2: (no value)

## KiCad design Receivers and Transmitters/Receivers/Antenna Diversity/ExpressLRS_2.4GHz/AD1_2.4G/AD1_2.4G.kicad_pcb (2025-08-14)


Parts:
ANT1, ANT2: Conn_Coaxial; U.FL_Hirose_U.FL-R-SMT-1_Vertical
C1: 10uF; C_0603_1608Metric_Pad1.08x0.95mm_HandSolder
C2: 1uF; C_0603_1608Metric_Pad1.08x0.95mm_HandSolder
C3: 47uF; C_0603_1608Metric_Pad1.08x0.95mm_HandSolder
CR1: SMBJ60A; SMBJSeries_LTF
F1: MF-PSMF020X-2; FUSE_F020X_BRN
J1: Conn_01x04_Pin; JST_GH_SM04B-GHS-TB_1x04-1MP_P1.25mm_Horizontal
J2: Conn_01x04_Socket; Harwin_M20-89004xx_1x04_P2.54mm_Horizontal
U1: TPS7A4701xRGW; Texas_RGW0020A_VQFN-20-1EP_5x5mm_P0.65mm_EP3.15x3.15mm_Ther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

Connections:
+3.3V: C3.1, U1.1 (OUT), U1.20 (OUT); also elsewhere on the board
+5V: F1.1, J1.1, J2.1
/RX: J1.3, J2.3; also elsewhere on the board
/SE2431L/ANT1: ANT1.1 (In); also elsewhere on the board
/SE2431L/ANT2: ANT2.1 (In); also elsewhere on the board
/TX: J1.2, J2.2; also elsewhere on the board
F2: C1.1, CR1.1, F1.2, U1.13 (EN), U1.15 (IN), U1.16 (IN)
GND: ANT1.2 (Ext), ANT2.2 (Ext), C1.2, C2.2, C3.2, CR1.2, J1.4, J2.4, U1.7 (GND), U1.8 (1.6V), U1.11 (0.2V), U1.12 (0.1V), U1.21 (EP); also elsewhere on the board
unnamed: C2.1, U1.14 (NR)

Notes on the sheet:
ExpressLRS
Pads, Headers and Connectors
Paschalis M.
Low-Noise RF LDO Regulator with TVS and Fuse Input Protection
ExpressLRS_2.4GHz_RX
The SkyWorks SE2431L is an excellent RF front-end module designed for the 2.4 GHz ISM band, offering an integrated Power Amplifier (PA), Low Noise Amplifier (LNA), and antenna diversity switch.


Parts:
C16, C17: 100nF; C_0603_1608Metric_Pad1.08x0.95mm_HandSolder
C18: 470nF; C_0603_1608Metric_Pad1.08x0.95mm_HandSolder
C19, C20: 10nF; C_0603_1608Metric_Pad1.08x0.95mm_HandSolder
FL1: 2450FM07D0034T; Mouser Part Number 609-2450FM07D0034T
U2: SX1280IMLTRT; QFN24_4X4_SEM
Y1: 52MHz; Crystal_SMD_2016-4Pin_2.0x1.6mm

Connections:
+3.3V: C16.1, C17.1, U2.11 (VBAT_IO), U2.15 (VBAT); also elsewhere on the board
/ESP8285/BUSY: U2.7 (BUSY); also elsewhere on the board
/ESP8285/DIO1: U2.8 (DIO1); also elsewhere on the board
/ESP8285/NSS_CTS: U2.19 (NSS_CTS); also elsewhere on the board
/ESP8285/SX_MISO: U2.16 (MISO_TX); also elsewhere on the board
/ESP8285/SX_MOSI: U2.17 (MOSI_RX); also elsewhere on the board
/ESP8285/SX_NRESET: U2.3 (NRESET); also elsewhere on the board
/ESP8285/SX_SCK: U2.18 (SCK_RTSN); also elsewhere on the board
/SE2431L/TR: FL1.3 (OUT); also elsewhere on the board
/SX1280/RFIO: FL1.1 (IN), U2.22 (RFIO)
/SX1280/VDD_INN: C18.1, C20.1, U2.2 (VDD_INN), U2.12 (DCC_FB)
GND: C16.2, C17.2, C18.2, C19.1, C20.2, FL1.2 (GND_1), FL1.4 (GND_2), U2.5 (GND), U2.13 (GND), U2.20 (GND), U2.21 (GND), U2.23 (GND), U2.24 (GND), U2.25 (GND), Y1.2, Y1.4; also elsewhere on the board
unnamed: C19.2, U2.1 (VR_PA)
unnamed: U2.4 (XTA), Y1.3
unnamed: U2.6 (XTB), Y1.1

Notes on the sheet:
2.45GHz Impedance Matched Low Pass Filter Optimized for Semtech SX1280 and SX1281 chipsets
2450FM07D0034001T (LOW PASS FILTER)
Paschalis M.
LoRa Connect RF Transceiver SX1280


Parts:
C4: 2.2uF; C_0603_1608Metric_Pad1.08x0.95mm_HandSolder
C5, C6: 10pF; C_0603_1608Metric_Pad1.08x0.95mm_HandSolder
C7: 100nF; C_0603_1608Metric_Pad1.08x0.95mm_HandSolder
R1: 2.2K; R_0603_1608Metric_Pad0.98x0.95mm_HandSolder
R9: 1.2K; R_0603_1608Metric_Pad0.98x0.95mm_HandSolder
R10: 10K; R_0603_1608Metric_Pad0.98x0.95mm_HandSolder
U4: SE2431L-R; SE2431L_SKY

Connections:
+3.3V: U4.20 (CSD), U4.21 (CPS); also elsewhere on the board
/ESP8285/ANT_SEL: U4.16 (ANT_SEL); also elsewhere on the board
/ESP8285/CTX: R10.2, U4.24 (CTX); also elsewhere on the board
/SE2431L/ANT1: U4.15 (ANT1); also elsewhere on the board
/SE2431L/ANT2: U4.13 (ANT2); also elsewhere on the board
/SE2431L/BOUT: R1.2, R9.2, U4.23 (BOUT)
/SE2431L/TR: U4.6 (T/R); also elsewhere on the board
/SE2431L/VCC1: C4.1, C5.1, U4.22 (VCC1)
/SE2431L/VCC2: C6.1, C7.1, U4.19 (VCC2)
GND: C4.2, C5.2, C6.2, C7.2, R10.1, U4.9 (GND), U4.10 (GND), U4.11 (GND), U4.12 (GND), U4.14 (GND), U4.18 (GND), U4.25 (EPAD); also elsewhere on the board
unnamed: R9.1, U4.2 (B1)
unnamed: R1.1, U4.1 (B2)

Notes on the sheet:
Paschalis M.
SE2431L is an RF front-end module designed for the 2.4 GHz ISM band, offering an integrated Power Amplifier (PA), Low Noise Amplifier (LNA), and antenna diversity switch.

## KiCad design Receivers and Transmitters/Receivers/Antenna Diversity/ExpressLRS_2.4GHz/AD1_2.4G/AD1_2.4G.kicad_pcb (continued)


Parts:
ANT3: W3008; ANTENNA_W3008
C21, C22: 10pF; C_0603_1608Metric_Pad1.08x0.95mm_HandSolder
C23, C24, C25, C26, C27, C28, C29: 100nF; C_0603_1608Metric_Pad1.08x0.95mm_HandSolder
C30, C32: 10uF; ECASD40J106M055K00
C31: 0.1uF; C_0603_1608Metric_Pad1.08x0.95mm_HandSolder
C33: 1.5pF; C_0402_1005Metric_Pad0.74x0.62mm_HandSolder
D1: LED; LED_0603_1608Metric_Pad1.05x0.95mm_HandSolder
JP2: Jumper_2_Small_Bridged; TestPoint_2Pads_Pitch2.54mm_Drill0.8mm
R2, R3, R7, R8: 10K; R_0603_1608Metric_Pad0.98x0.95mm_HandSolder
R4: 12K; R_0603_1608Metric_Pad0.98x0.95mm_HandSolder
R5: 0; R_0603_1608Metric_Pad0.98x0.95mm_HandSolder
R6: 1K; R_0603_1608Metric_Pad0.98x0.95mm_HandSolder
U3: ESP8285H16; QFN32_5X5_EXP
Y2: 26MHz; Crystal_SMD_2016-4Pin_2.0x1.6mm

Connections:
+3.3V: C23.1, C24.1, C25.1, C26.1, C27.1, C28.1, C29.1, C30.2, R3.1, R7.1, R8.1, U3.1 (VDDA), U3.3 (VDD3P3), U3.4 (VDD3P3), U3.11 (VDDPST), U3.17 (VDDPST), U3.29 (VDDD), U3.30 (VDDA), U3.32 (EXT_RSTB); also elsewhere on the board
/ESP8285/ANT_SEL: U3.18 (SD_DATA_2); also elsewhere on the board
/ESP8285/BUSY: U3.24 (GPIO5); also elsewhere on the board
/ESP8285/CTX: U3.19 (SD_DATA_3); also elsewhere on the board
/ESP8285/DIO1: U3.16 (GPIO4); also elsewhere on the board
/ESP8285/LED: R5.1, U3.8 (XDP_DCDC)
/ESP8285/NSS_CTS: R2.2, U3.13 (MTDO); also elsewhere on the board
/ESP8285/SX_MISO: U3.10 (MTDI); also elsewhere on the board
/ESP8285/SX_MOSI: U3.12 (MTCK); also elsewhere on the board
/ESP8285/SX_NRESET: R3.2, U3.14 (GPIO2); also elsewhere on the board
/ESP8285/SX_SCK: U3.9 (MTMS); also elsewhere on the board
/RX: U3.25 (U0RXD); also elsewhere on the board
/TX: U3.26 (U0TXD); also elsewhere on the board
GND: ANT3.G1, ANT3.G2, C21.2, C22.2, C23.2, C24.2, C25.2, C26.2, C27.2, C28.2, C29.2, C30.1, C31.1, C32.1, C33.2, D1.1 (K), JP2.2 (B), R2.1, R4.2, U3.33 (GND), Y2.2, Y2.4; also elsewhere on the board
unnamed: D1.2 (A), R6.2
unnamed: JP2.1 (A), R8.2, U3.15 (GPIO0)
unnamed: R5.2, R6.1
unnamed: C31.2, C32.2, R7.2, U3.7 (CHIP_EN)
unnamed: ANT3.FEED, C33.1, U3.2 (LNA)
unnamed: R4.1, U3.31 (RES12K)
unnamed: C22.1, U3.28 (XTAL_IN), Y2.3
unnamed: C21.1, U3.27 (XTAL_OUT), Y2.1

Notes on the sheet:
--> Serial connection with a 12 kΩ resistor and connect to the ground
--> External reset signal (Low voltage level: active)
Decoupling Capacitors
ExpressLRS LED Indicator
Tantalum Cap
Paschalis M.
--> Connect to SE2435L (CTX: Transmit enable control input)
ESP8285



Board: 6 copper layers, 39.5 x 39.5 mm, 55 parts (17 on the bottom side), 38 nets.

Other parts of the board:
hole1, hole4: MountingHole_4mm
hole2, hole3: (no value)

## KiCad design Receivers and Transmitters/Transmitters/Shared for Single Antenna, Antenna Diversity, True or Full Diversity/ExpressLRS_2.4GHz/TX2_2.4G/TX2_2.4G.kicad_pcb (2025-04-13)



Board: 4 copper layers, 39.8 x 55.8 mm, 11 parts (5 on the bottom side), 16 nets.

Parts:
C1: 10uF; C_0603_1608Metric_Pad1.08x0.95mm_HandSolder
C2: 1uF; C_0603_1608Metric_Pad1.08x0.95mm_HandSolder
C3: 47uF; C_0603_1608Metric_Pad1.08x0.95mm_HandSolder
D1: WS2812B-2020; LED_WS2812B-2020_PLCC4_2.0x2.0mm
J1: Conn_01x05_Socket; JST_XH_B5B-XH-A_1x05_P2.50mm_Vertical
J2: Conn_01x03_Socket; JST_XH_B3B-XH-A_1x03_P2.50mm_Vertical
J3: Conn_01x04_Socket; JST_XH_B4B-XH-A_1x04_P2.50mm_Vertical
R1: 10K; R_0603_1608Metric_Pad0.98x0.95mm_HandSolder
U1: TPS7A4701xRGW; Texas_RGW0020A_VQFN-20-1EP_5x5mm_P0.65mm_EP3.15x3.15mm_Ther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
U2: ESP32-WROOM-32
U3: E28-2G4M27S; E28

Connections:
+3.3V: C3.1, J1.4, J2.2, J3.3, R1.1, U1.1 (OUT), U1.20 (OUT), U2.2 (VDD), U3.1 (VCC)
+5V: C1.1, D1.4 (VDD), U1.13 (EN), U1.15 (IN), U1.16 (IN)
/BOOT0: J1.1, U2.25 (IO0)
/LED_RGB: D1.3 (DIN), U2.23 (IO15)
/MISO: U2.31 (IO19), U3.3 (MISO_TX)
/MOSI: U2.37 (IO23), U3.4 (MOSI_RX)
/NSS: U2.29 (IO5), U3.6 (NSS_CTS)
/RX: J1.3, U2.34 (RXD0/IO3)
/RX_EN: U2.12 (IO27), U3.8 (RX_EN)
/SCK: J3.1, U2.30 (IO18), U3.5 (SCK_RTSN)
/SDA: J3.2, U2.22 (SDI/SD1)
/SPORT: J2.1, U2.16 (IO13)
/TX: J1.2, U2.35 (TXD0/IO1)
GND: C1.2, C2.2, C3.2, D1.2 (VSS), J1.5, J2.3, J3.4, U1.7 (GND), U1.8 (1.6V), U1.11 (0.2V), U1.12 (0.1V), U1.21 (EP), U2.1 (GND), U2.15 (GND), U2.38 (GND), U2.39 (GND), U3.2 (GND), U3.7 (GND)
unnamed: C2.1, U1.14 (NR)
unnamed: R1.2, U2.3 (EN)

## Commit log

2025-01-11 Added README detailing transmission modes: Single Antenna, Antenna Diversity, True Diversity, Gemini Mode, and Gemini Xrossband GemX.
2025-01-11 Added "Go Back to Main README" button at the bottom of Receivers and Transmitters README
2025-01-12 Added .gitignore for KiCad PCB project to exclude temporary and exported files
2025-01-16 Added KiCad project files for the AD1_2.4GHz Antenna Diversity RX board.
    [AD1_2.4G.kicad_pcb, AD1_2.4G.kicad_sch, ESP8285.kicad_sch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]
2025-01-27 Added site files to docs for Custom RX/TX Board Designs overview
2025-02-25 Added True Antenna Diversity receiver implementation
    [ESP32.kicad_sch, RFX2401C_ANT1.kicad_sch, RFX2401C_ANT2.kicad_sch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]
2025-03-15 Update True Antenna Diversity TD1_2.4G KiCad schematics and PCB design
    [ESP32.kicad_sch, RFX2401C_ANT1.kicad_sch, RFX2401C_ANT2.kicad_sch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]
2025-03-15 Update README.md with latest TX/RX board details
2025-03-18 Added BOM and updated README, removed obsolete KiCad files
    [AD1_2.4G.kicad_pcb, AD1_2.4G.kicad_sch, AD2_900M.kicad_pcb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]
2025-03-30 Updated hardware setup image, README, and KiCad project files for TX1_2.4G
    [TX1_2.4G.kicad_pcb, TX1_2.4G.kicad_sch]
2025-03-30 Added new images and TX2_2.4G project files
    [(PCB outline) V1_Matek_mLRS-JRBay-btm (with PCB mounting).DXF, TX2_2.4G.kicad_pcb, TX2_2.4G.kicad_sch]
2025-03-30 Added TX board images and file links in README under 'TX Boards (Shared for Single Antenna, Antenna Diversity & True Diversity)' section
2025-03-31 Updated links in README files, modified hardware setup image, and added TX3_2.4G assets (images & videos).
    [ESP8285.kicad_sch, TX3_2.4G.kicad_pcb, TX3_2.4G.kicad_sch]
2025-04-10 Updated schematics for TD1_2.4G receiver: ESP32, SX1280, and RFX2401C blocks
    [ESP32.kicad_sch, RFX2401C_ANT1.kicad_sch, RFX2401C_ANT2.kicad_sch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]
2025-04-12 Add Gemini Mode (Single Band) TX board files and PCB preview video (G_TX1.mp4)
    [ESP8285.kicad_sch, G_TX1.kicad_pcb, G_TX1.kicad_sch]
2025-04-13 Add Gemini Mode (Single Band) TX board image and documentation updates - Updated hardware setup to include Gemini TX - Added G_TX1_2.4G preview image - Updated KiCad schematic with LNA section and 5.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
    [ESP8285.kicad_sch, G_TX1.kicad_pcb, G_TX1.kicad_sch]
2025-04-13 Fixed incorrect LED RGB connection to ESP32 on TX2_2.4G and TX3_2.4G schematics and PCBs
    [TX2_2.4G.kicad_pcb, TX2_2.4G.kicad_sch, TX3_2.4G.kicad_pcb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]
2025-04-13 Update Gemini TX board video preview - Reflects updated PCB layout with LNA section - Includes 5.6pF matching capacitor for 50Ω impedance
2025-04-14 Fix URL spacing in Gemini Mode (Single Band) TX board preview link
2025-05-19 Uploaded V1.2 STL for Top_Bottom_Offset
    After physical verification, 3 more configurations will be uploaded.
    [V1.2 (Top_Bottom_Offset)_Matek_mLRS-JRBay-btm.STL, V1.2 (Top_Bottom_Offset)_Matek_mLRS_JRBay_cover.STL]
2025-08-14 Update Antenna Diversity (AD1_2.4G), True Antenna Diversity (TD1_2.4G), and Gemini Mode transmitter (G_TX1): Modify KiCad files, add BOMs and production files; update images, docs, videos, and README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
    [AD1_2.4G.kicad_pcb, AD1_2.4G.kicad_sch, ESP32.kicad_sch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]
2025-08-15 Update IBOM files with renamed HTML outputs and refresh images, KiCad project, README, and docs
2025-08-27 Update G_TX1 Freecad for enclosure and KiCad files (schematics, PCB, and project) - added fan pin headers
    [ESP8285.kicad_sch, Enclosure_Bottom.stl, Enclosure_Top.stl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]
2025-09-10 Update AD1_2.4G: schematic revisions, project file, and README
    [AD1_2.4G.kicad_sch]
2025-09-10 Update TD1_2.4G: schematic and PCB revisions, BOM export, README; remove old PCBWay production files
    [ESP32.kicad_sch, RFX2401C_ANT1.kicad_sch, RFX2401C_ANT2.kicad_sch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]
2025-09-10 Update G_TX1: PCB layout, project file, schematic, and README
    [G_TX1.kicad_pcb, G_TX1.kicad_sch]
